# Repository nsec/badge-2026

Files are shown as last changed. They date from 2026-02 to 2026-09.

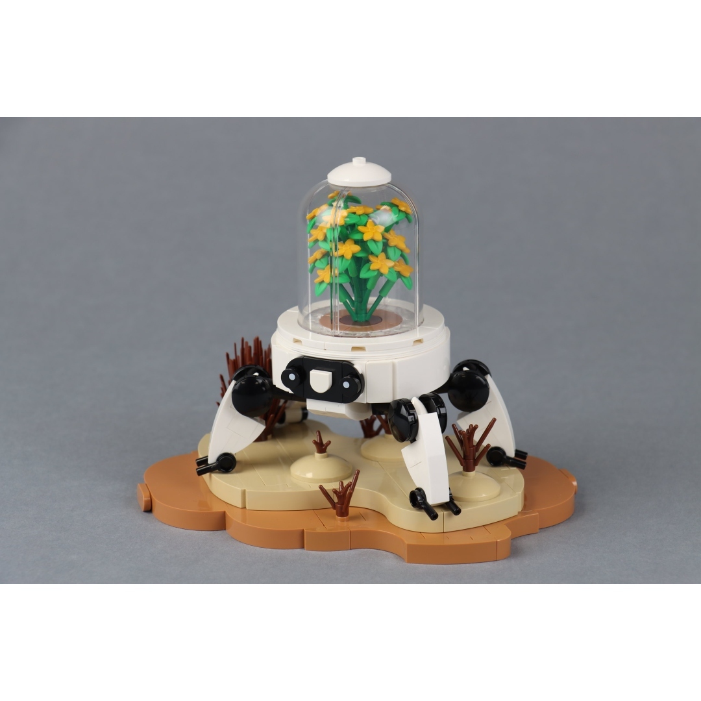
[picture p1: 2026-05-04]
hardware/sao/Sao_robotplant/625359624_18107269357665788_6827108831125513139_n.jpg

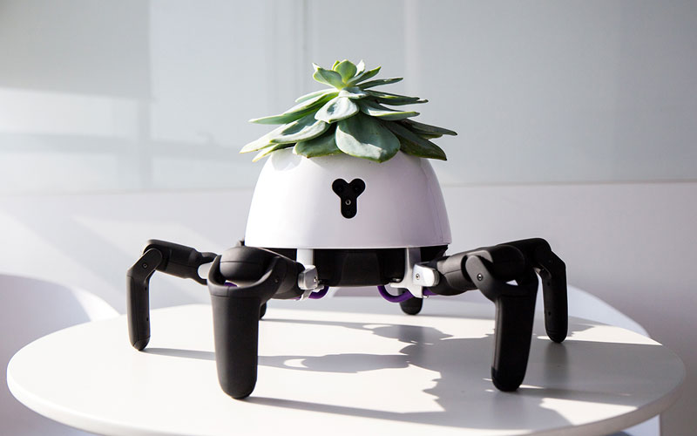
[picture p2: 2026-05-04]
hardware/sao/Sao_robotplant/guy-gives-plant-robotic-legs-so-it-can-experience-animal-like-freedom-1.jpg

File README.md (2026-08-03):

# NorthSec Badge 2026 Firmware (ESP32-S3)

Bare-bones firmware scaffold for the **NorthSec 2026 CTF badge**, targeting **ESP32-S3**.

Design goals (repo requirements):

- **Arduino framework**, but **no `.ino`** (pure C++ entrypoint)
- **PlatformIO-based** build (produces flashable `.bin` outputs)
- **Two concurrent firmware images** via partitions: **`conference`** and **`ctf`**
- A simple **serial CLI**, including a command to **switch which firmware boots next**
- Clear hierarchy separating:
  - `lib/core/` → hardware/system modules
  - `lib/challenges/` → CTF challenge modules
- GitHub Actions workflow builds on PR/push to `main`, and **publishes artifacts on version tags**

## Repo layout

```
src/
  main.cpp                     C++ Arduino entrypoint (no .ino)

lib/
  core/
    cli/                        Serial command line
    system/                     OTA boot selection / dual-firmware helpers
    hardware/                   Hardware abstraction (pins, drivers)
  challenges/
    registry.*                  Challenge init/tick hooks
    example_challenge.*         Placeholder challenge module

partitions/
  badge_factory_ota.csv         Partition table (conference + ctf)

.github/workflows/
  build.yml                     CI build + tag-based release

platformio.ini                  PlatformIO project config
```

## PlatformIO + Arduino (no .ino)

This project uses PlatformIO with the Arduino framework.
The entrypoint is `src/main.cpp` (standard Arduino `setup()` / `loop()`), not a `.ino`.

## Dual firmware: `conference` + `ctf`

The partition table `partitions/badge_factory_ota.csv` defines:

- `conference` (app) — a "golden" image
- `ctf` (app) — an alternate/updated image
- `otadata` (data) — controls which app partition boots next

### How switching works

Under Arduino-ESP32, you can call ESP-IDF’s OTA APIs. This repo wraps them in:

- `lib/core/system/ota_manager.*`

That module provides:

- `core::ota::printBootInfo(Stream&)`
- `core::ota::setNextBoot(BootTarget, Stream&)`

## Serial CLI

The CLI is implemented in `lib/core/cli/` and runs over `Serial` at **115200**.

Commands:

- `help`
- `info` — print running partition and configured boot partition
- `boot conference` — set *next boot* to `conference` and reboot
- `boot ctf` — set *next boot* to `ctf` and reboot
- `reboot`

## Building locally

### Prerequisites

- **VS Code** with **PlatformIO IDE extension** installed, **OR**
- **PlatformIO Core** (CLI) installed

### Windows Setup (Important!)

**This project uses ESP-IDF framework to avoid Windows path-length issues with Arduino-ESP32 SDK extraction.**

Before building, set a short PlatformIO core directory to prevent path issues:

```powershell
# Set environment variable permanently (restart VS Code after)
setx PLATFORMIO_CORE_DIR C:\pio
```

Then **restart VS Code** or your terminal.

### First-Time Setup

1. Clone this repository:
   ```powershell
   git clone https://github.com/yourusername/badge-2026.git
   cd badge-2026
   ```

2. Set the short core directory (Windows only, see above)

3. Open the project in VS Code with PlatformIO extension, or use CLI

### Build

**In VS Code:** Click the PlatformIO "Build" button (checkmark icon) in the bottom toolbar

**Or via CLI:**
```powershell
# Build for conference partition (default)
C:\pio\penv\Scripts\platformio.exe run -e esp32-s3-devkitc-1-conference

# Or if platformio is in PATH
pio run
```

First build will download Arduino-ESP32 framework and toolchains. Subsequent builds are much faster.

### Dual Firmware Build

The badge uses a **conference + CTF** partition layout for dual-firmware boot:

- **conference** partition (`0x10000`) - Conference/stable image
- **ctf** partition (`0x150000`) - CTF challenges image

**To flash both partitions:**

```powershell
# 1. Upload to conference partition
C:\pio\penv\Scripts\platformio.exe run -e esp32-s3-devkitc-1-conference -t upload

# 2. Upload the CTF firmware to ctf partition
C:\pio\penv\Scripts\platformio.exe run -e esp32-s3-devkitc-1-ctf -t upload
```

**In VS Code:** Use the environment switcher in the bottom toolbar to select `esp32-s3-devkitc-1-conference` or `esp32-s3-devkitc-1-ctf`, then click Upload.

After flashing both, you can use the badge CLI commands to switch between them:
- `boot conference` - Set next boot to conference partition
- `boot ctf` - Set next boot to ctf partition
- `info` - Show current boot partition

Build outputs (including flashable binaries) appear under:

- `.pio/build/<env>/firmware.bin`
- `.pio/build/<env>/bootloader.bin`
- `.pio/build/<env>/partitions.bin`

### Flash

If you have a board connected and the correct upload port set:

```powershell
pio run -t upload
```

### Monitor

```powershell
pio device monitor
```

## Native Simulator

A desktop simulator allows running the badge firmware on your development machine
without hardware. Useful for testing CLI commands, debugging, and development.

### Prerequisites

- PlatformIO Core (CLI)
- GCC with C++17 and pthread support (Linux/macOS)
- For Windows: WSL recommended

### First-Time Setup

Initialize the FreeRTOS submodule:

```bash
git submodule update --init --recursive
```

### Build

```bash
pio run -e native
```

### Run

```bash
./.pio/build/native/program
```

The simulator presents the same CLI as the real badge. Press `Ctrl+C` to exit.

## CI/CD - GitHub Actions Workflow

### Automated Builds

The workflow in `.github/workflows/build.yml` automatically builds firmware on:

- **Pull Requests** targeting `main` - Build verification
- **Push to `main`** - Build and upload artifacts
- **Version Tags** (`v*`) - Build, create GitHub Release with binaries

### What Gets Built

Both firmware variants are built in parallel:
- **Conference firmware** (`badge-conference.bin`) - Conference mode with schedule and social features
- **CTF firmware** (`badge-ctf.bin`) - CTF challenges mode
- Supporting files: `bootloader.bin`, `partitions.bin`

### Creating a Release

**Step 1: Open a Pull Request**
```bash
git checkout -b feature-my-changes
# Make your changes
git add .
git commit -m "Add new feature"
git push origin feature-my-changes
```
Open PR on GitHub targeting `main` branch. GitHub Actions will build and verify.

**Step 2: Merge to Main**
After review, merge the PR. This triggers a build and uploads artifacts.

**Step 3: Create a Release Tag**
```bash
# Pull latest main
git checkout main
git pull origin main

# Create and push version tag
git tag v1.0.0
git push origin v1.0.0
```

Or use GitHub's web interface:
1. Go to repository → Releases → "Create a new release"
2. Click "Choose a tag" → Type new tag (e.g., `v1.0.0`) → "Create new tag"
3. Set release title (e.g., "NorthSec Badge 2026 v1.0.0")
4. GitHub Actions will automatically build and attach binaries

### Release Artifacts

Each release includes:
- `badge-conference.bin` - Conference firmware for conference partition
- `badge-ctf.bin` - CTF challenges firmware for CTF partition
- `bootloader.bin` - ESP32-S3 bootloader
- `partitions.bin` - Partition table
- `FLASH_INSTRUCTIONS.txt` - Complete flashing guide

## Flashing Pre-Built Firmware

### Prerequisites

Install esptool:
```bash
pip install esptool
```

Find your serial port:
- **Windows**: Check Device Manager → Ports (COM & LPT) → Look for "USB Serial Device" (e.g., COM4)
- **Linux**: `ls /dev/ttyACM* /dev/ttyUSB*` (usually /dev/ttyACM0)
- **Mac**: `ls /dev/cu.*` (look for cu.usbmodem*)

### Download Release Files

Go to [Releases](https://github.com/yourusername/badge-2026/releases) and download the latest `.zip` or individual files.

### Flash All (Recommended for New Badges)

Flash bootloader, partition table, and both firmware images:

**Windows:**
```powershell
python -m esptool --chip esp32s3 --port COM4 --baud 460800 ^
  --before default_reset --after hard_reset write_flash -z ^
  --flash_mode dio --flash_freq 80m --flash_size 8MB ^
  0x0 bootloader.bin ^
  0x8000 partitions.bin ^
  0x10000 badge-conference.bin ^
  0x150000 badge-ctf.bin
```

**Linux/Mac:**
```bash
python3 -m esptool --chip esp32s3 --port /dev/ttyACM0 --baud 460800 \
  --before default_reset --after hard_reset write_flash -z \
  --flash_mode dio --flash_freq 80m --flash_size 8MB \
  0x0 bootloader.bin \
  0x8000 partitions.bin \
  0x10000 badge-conference.bin \
  0x150000 badge-ctf.bin
```

### Update Only Firmware (Keep Existing Bootloader/Partitions)

If badges are already initialized, flash only updated firmware:

**Conference firmware only:**
```bash
python -m esptool --chip esp32s3 --port <PORT> --baud 460800 \
  write_flash -z 0x10000 badge-conference.bin
```

**CTF firmware only:**
```bash
python -m esptool --chip esp32s3 --port <PORT> --baud 460800 \
  write_flash -z 0x150000 badge-ctf.bin
```

**Both firmwares:**
```bash
python -m esptool --chip esp32s3 --port <PORT> --baud 460800 \
  write_flash -z 0x10000 badge-conference.bin 0x150000 badge-ctf.bin
```

### Verify Flash

Connect to serial console at 115200 baud:
```bash
# Windows
python -m serial.tools.miniterm COM4 115200

# Linux/Mac
python3 -m serial.tools.miniterm /dev/ttyACM0 115200
```

You should see the boot banner and CLI prompt. Type `help` to see available commands.

### Switch Between Firmwares

At the CLI prompt:
- `boot conference` - Reboot to conference firmware
- `boot ctf` - Reboot to CTF challenges firmware
- `info` - Show current running partition

## Additional Documentation

- **[FLASHING.md](FLASHING.md)** - Complete flashing guide for mass production and distribution
- **[CONTRIBUTING.md](CONTRIBUTING.md)** - Developer guide for adding features and challenges
- **[.github/workflows/build.yml](.github/workflows/build.yml)** - CI/CD configuration reference

## Firmware Architecture

### Dual-Firmware Design

This badge uses a unique dual-firmware architecture:

- **Conference Partition (0x10000)** - Conference mode
  - Boots by default on new badges
  - Contains conference-specific features (schedule, social, etc.)
  - Libraries: `core` + `conference`
  
- **CTF Partition (0x150000)** - CTF Challenges mode
  - Accessible via `boot ctf` command
  - Contains competition challenges (crypto, hardware, etc.)
  - Libraries: `core` + `challenges`

Both firmwares share the `core` library (CLI, OTA management, hardware abstraction) but have completely different feature sets.

### Adding New Features

See [CONTRIBUTING.md](CONTRIBUTING.md) for detailed instructions on adding:
- Conference modules (conference firmware)
- Challenge modules (CTF firmware)
- Core utilities (shared by both)

## License

Apache-2.0 (see `LICENSE`).

## Credits
NorthSec CTF badge 2026 is brought to you by the teamwork of:

 - [20th](https://github.com/20th)
 - [Svieg](https://github.com/Svieg)
 - [TheKGBSpy](https://github.com/TheKGBSpy)
 - [jgalar](https://github.com/jgalar)
 - [lle](https://github.com/lle)
 - [mjeanson](https://github.com/mjeanson)
 - [nyx0](https://github.com/nyx0)
 - [p0ns](https://github.com/p0ns)
 - [padraignix](https://github.com/padraignix)

Special thanks to:
 - [Marc-Olivier](https://github.com/D3c4f-NS)
 - David

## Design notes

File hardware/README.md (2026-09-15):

This folder contains the design files of the NorthSec 2026 badge.

## Folder structure

| Folder | Content |
|:---|:---|
| boards | Kicad schematics & pcb layout |
| datasheets | datasheets of used electrical components |
| mechanical | Full FreeCAD 3d model of all components of flower |

## Schematic

**Interactive schematic:**

- [Open Badge schematics in KiCanvas](https://kicanvas.org/?repo=https%3A%2F%2Fgithub.com%2Fnsec%2Fbadge-2026%2Ftree%2Fmain%2Fhardware%2Fbadge)
- [Open Sun SAO schematics in KiCanvas](https://kicanvas.org/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)
- [Open Tree SAO schematics in KiCanvas](https://kicanvas.org/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)
- [Open Robotplant SAO schematics in KiCanvas](https://kicanvas.org/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)

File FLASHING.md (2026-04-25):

# Badge Flashing Guide

## Two Distribution Modes

The badge firmware supports two release packages:

| Mode | Use Case | Contents |
|---|---|---|
| **conference-only** | Pre-CTF badge distribution | Conference firmware only, no `swapboot`, no CTF code |
| **dual** | Full badge experience | Conference + CTF firmware, `swapboot` enabled |

## Requirements

- Python 3.7+ with esptool: `pip install esptool`
- USB-C data cable
- Badge firmware package from GitHub release

## Quick Flash (Recommended)

Each release package includes `flash.py`. Extract the package and run:

```bash
# Conference-only (pre-CTF distribution)
python flash.py --mode conference-only --port <PORT>

# Dual firmware (full badge)
python flash.py --mode dual --port <PORT>
```

### Options

| Flag | Description |
|---|---|
| `--mode` | `conference-only` or `dual` (required for flashing) |
| `--port` | Serial port, e.g. `COM4` or `/dev/ttyACM0` (auto-detect if omitted) |
| `--all` | Flash ALL detected ESP32-S3 badges in parallel |
| `--baud` | Baud rate (default: 460800) |
| `--dry-run` | Print the esptool command without executing |
| `--bin-dir` | Directory containing binaries (default: script directory) |
| `--list-ports` | Show all serial ports and exit |

### Examples

```bash
# Single badge (auto-detect port — works on Windows, macOS, Linux)
python flash.py --mode dual

# Single badge with explicit port
python flash.py --mode dual --port COM4              # Windows
python3 flash.py --mode conference-only --port /dev/ttyACM0  # Linux
python3 flash.py --mode dual --port /dev/cu.usbmodem*  # macOS

# Multi-flash: flash ALL connected badges at once
python flash.py --mode conference-only --all

# Preview without flashing
python flash.py --mode dual --all --dry-run

# Debug port detection
python flash.py --list-ports
```

### Erase (Wipe Badge Clean)

```bash
# Erase a single badge
python flash.py --erase

# Erase a specific port
python flash.py --erase --port COM4

# Erase ALL connected badges
python flash.py --erase --all
```

After erasing, reflash with the desired mode.

### Multi-Flash (Mass Production)

Connect multiple badges via USB hubs, then:

```bash
python flash.py --mode conference-only --all
```

All detected ESP32-S3 badges flash in parallel. A summary report shows success/failure per port.

## Manual Flash (esptool)

### Conference-Only

```bash
python -m esptool --chip esp32s3 --port <PORT> --baud 460800 \
  --before default_reset --after hard_reset write_flash -z \
  --flash_mode dio --flash_freq 80m --flash_size 8MB \
  0x0 bootloader.bin \
  0x8000 partitions.bin \
  0x10000 badge-conference.bin \
  0x2A2000 spiffs-conference.bin
```

### Dual Firmware

```bash
python -m esptool --chip esp32s3 --port <PORT> --baud 460800 \
  --before default_reset --after hard_reset write_flash -z \
  --flash_mode dio --flash_freq 80m --flash_size 8MB \
  0x0 bootloader.bin \
  0x8000 partitions.bin \
  0x10000 badge-conference.bin \
  0x150000 badge-ctf.bin \
  0x2A2000 spiffs-ctf.bin
```

## Memory Map

| Address | Size | Content | Present In |
|---|---|---|---|
| 0x0 | ~15KB  | bootloader.bin | Both modes |
| 0x8000 | 3KB | partitions.bin | Both modes |
| 0xE000 | 8KB | OTA data selector | Auto |
| 0x10000 | 1.25MB | badge-conference.bin | Both modes |
| 0x150000 | 1.25MB | badge-ctf.bin | Dual only |
| 0x290000 | 64KB | Core dump partition  | Auto |
| 0x2A2000 | ~1.4MB | SPIFFS filesystem | Both (mode-specific)|

## Verification Checklists

### Conference-Only

After flashing:
- [ ] Boot banner shows `Mode: conference-only`
- [ ] CLI `help` does NOT list `swapboot`
- [ ] LED heartbeat blinks
- [ ] CLI commands respond

### Dual Firmware

After flashing:
- [ ] Boot banner shows `Mode: conference (dual)`
- [ ] CLI `help` lists `swapboot`
- [ ] `swapboot` reboots to CTF firmware
- [ ] CTF boot banner shows `Mode: ctf`
- [ ] `swapboot` returns to conference firmware

## Troubleshooting

**"Failed to connect":**
- Hold BOOT button while connecting USB
- Try lower baud rate: `--baud 115200`
- Check USB cable supports data (not charge-only)

**Badge not working after flash:**
- Erase flash: `python -m esptool --chip esp32s3 --port <PORT> erase_flash`
- Reflash all files

**Wrong partition boots:**
- Use CLI `swapboot` command
- Or reflash with the correct package

## Support

For issues: https://github.com/nsec/badge-2026/issues

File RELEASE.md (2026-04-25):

# Release Process

For maintainers creating firmware releases.

## Two Release Modes

Every release produces **two** packages:

| Package | Purpose | Contents |
|---|---|---|
| `nsec2026-conference-only-vX.Y.Z.tar.gz` | Pre-CTF distribution | Conference firmware only, `swapboot` disabled |
| `nsec2026-dual-firmware-vX.Y.Z.tar.gz` | Full badge experience | Conference + CTF firmware, `swapboot` enabled |

## Build Environments

| PIO Environment | Build Flag | Used In |
|---|---|---|
| `esp32-s3-devkitc-1-conference` | `HAS_CONFERENCE=1` | Dual package |
| `esp32-s3-devkitc-1-conference-only` | `HAS_CONFERENCE=1 CONFERENCE_ONLY=1` | Conference-only package |
| `esp32-s3-devkitc-1-ctf` | `HAS_CHALLENGES=1` | Dual package |

## Pre-Release Testing

### Conference-Only
- [ ] Build succeeds: `pio run -e esp32-s3-devkitc-1-conference-only`
- [ ] Flash and verify boot banner shows `Mode: conference-only`
- [ ] CLI `help` does **not** show `swapboot`
- [ ] Validation passes: `python tools/validate_conference_only.py release/conference-only/`

### Dual Firmware
- [ ] Build succeeds: `pio run -e esp32-s3-devkitc-1-conference -e esp32-s3-devkitc-1-ctf`
- [ ] Conference boot banner shows `Mode: conference (dual)`
- [ ] `swapboot` switches to CTF firmware
- [ ] CTF boot banner shows `Mode: ctf`
- [ ] `swapboot` returns to conference firmware

### General
- [ ] All PRs merged to `main`
- [ ] No compilation warnings
- [ ] Memory usage acceptable

## Creating a Release

### Step 1: Build and Package Locally (Optional)

```bash
# Build all three environments (SPIFFS images are built automatically)
pio run -e esp32-s3-devkitc-1-conference-only
pio run -e esp32-s3-devkitc-1-conference
pio run -e esp32-s3-devkitc-1-ctf

# Package
python tools/package_release.py --version vX.Y.Z

# Validate conference-only package
python tools/validate_conference_only.py release/conference-only/
```

### Step 2: Tag and Push

```bash
git checkout main
git pull origin main
git tag -a v1.0.0 -m "Release v1.0.0"
git push origin v1.0.0
```

### Step 3: CI Builds Automatically

The GitHub Actions workflow will:
1. Build all three firmware environments (SPIFFS images are built automatically)
2. Package both release modes
3. Validate conference-only package (no CTF leaks)
4. Create GitHub Release with both archives

### Step 4: Verify Release

1. Go to Releases page
2. Verify two archives are attached:
   - `nsec2026-conference-only-vX.Y.Z.tar.gz`
   - `nsec2026-dual-firmware-vX.Y.Z.tar.gz`
3. Download and spot-check `manifest.json` in each

## Version Numbering

Semantic versioning: `vMAJOR.MINOR.PATCH`

- **MAJOR**: Breaking changes
- **MINOR**: New features (e.g. new challenge module)
- **PATCH**: Bug fixes

## CTF Content Safety

The conference-only release must **never** contain:
- CTF firmware binary (`badge-ctf.bin`)
- The `swapboot` CLI command
- Challenge code or strings (quantum, QAOA, VQE, etc.)
- Flag patterns (`NSEC{...}`)

**Guardrails in place:**
1. `CONFERENCE_ONLY` build flag compiles out `swapboot` and prevents `HAS_CHALLENGES`
2. `#error` in `badge_config.h` if both `CONFERENCE_ONLY` and `HAS_CHALLENGES` are set
3. `validate_conference_only.py` scans binary for forbidden patterns
4. CI runs validation on every build

## Adding New CTF Content

When adding new challenges:
1. Place code in `lib/challenges/<name>/`
2. Register in `lib/challenges/registry.cpp`
3. Update `tools/validate_conference_only.py` with new forbidden patterns if the challenge introduces distinctive strings
4. Verify conference-only validation still passes

## Hotfix Process

```bash
git checkout v1.0.0
git checkout -b hotfix/critical-bug
# ... fix ...
git commit -m "fix: resolve critical issue"
git push origin hotfix/critical-bug
# PR to main, then tag v1.0.1
```

## Rollback

1. Mark release as "Pre-release" in GitHub
2. Add warning to release notes
3. Point users to previous stable version

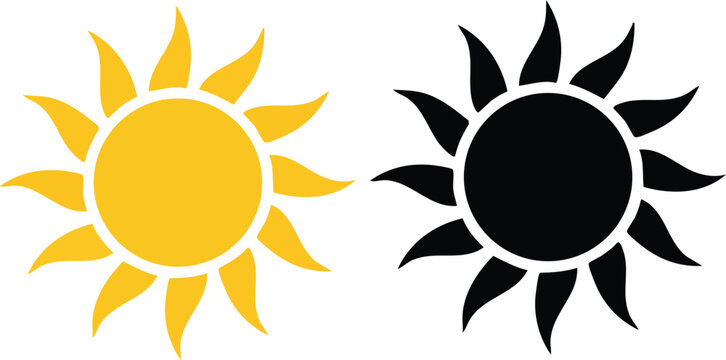
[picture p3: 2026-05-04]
hardware/sao/Sao_SUN/360_F_1957418534_RpFVAgXwyXc0LUIITzXDONv8gdVU5Ix7.jpg

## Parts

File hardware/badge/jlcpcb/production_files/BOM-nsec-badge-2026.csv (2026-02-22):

Comment | Designator | Footprint | LCSC | Quantity
0.1uF | C501,C502,C503,C504,C505,C506,C507,C508,C509,C510,C511,C512,C513,C514,C515,C516,C517,C518 | C_0603_1608Metric | C14663 | 18
0.1uF | C1101,C202 | C_0603_1608Metric | C28233 | 2
0.47 | R1202 | R_0603_1608Metric | C23411 | 1
100K | R805 | R_0603_1608Metric | C14675 | 1
100K | R302 | R_0603_1608Metric | C25803 | 1
10K | R201,R202,R204,R601,R602,R603,R604,R605,R606 | R_0603_1608Metric | C25804 | 9
10nF | C1001,C1003,C1006,C1009,C1011,C1013,C1015,C1019 | C_0603_1608Metric | C57112 | 8
10pF | C1032,C1035 | C_0603_1608Metric | C1634 | 2
10uF | C201,C302,C802 | C_0805_2012Metric | C15850 | 3
10uH | L1201 | L_Vishay_IFSC-1515AH_4x4x1.8mm | C222882 | 1
12pF | C1007,C1008 | C_0603_1608Metric | C38523 | 2
150pF | C1028,C1029 | C_0603_1608Metric | C1594 | 2
1K | R1001 | R_0603_1608Metric | C14676 | 1
1K | R203,R801,R802,R803 | R_0603_1608Metric | C21190 | 4
1R5 | R1004,R1005 | R_0603_1608Metric | C245932 | 2
1nF | C1017 | C_0603_1608Metric | C1588 | 1
1uF | C1004,C1201,C1202,C1203,C1204,C1205,C1206,C1207,C1208,C1209,C1211,C203,C301,C303 | C_0603_1608Metric | C15849 | 14
1uF | C803 | C_0805_2012Metric_Pad1.18x1.45mm_HandSolder | C28323 | 1
220pF | C1033,C1034 | C_0603_1608Metric | C1603 | 2
22nF | C1018 | C_0603_1608Metric | C21122 | 1
27.12Mhz | Y1001 | Crystal_SMD_3225-4Pin_3.2x2.5mm | C3003244 | 1
2u2F | C1002,C1005,C1010,C1012,C1014,C1016 | C_0603_1608Metric | C23630 | 6
33pF | C1023,C1024 | C_0603_1608Metric | C1663 | 2
390K | R804 | R_0603_1608Metric | C23150 | 1
4.7uF | C801 | C_0805_2012Metric_Pad1.18x1.45mm_HandSolder | C1779 | 1
4.7uF/50V | C1210,C1212 | C_1206_3216Metric | C29823 | 2
47pF | C1030,C1031 | C_0603_1608Metric | C1671 | 2
4u7F | C1020 | C_0603_1608Metric | C19666 | 1
5.1K | R301,R303,R401,R402 | R_0603_1608Metric | C23186 | 4
680pF | C1021,C1022 | C_0603_1608Metric | C107055 | 2
AP2112K-3_3TRG1 | U301 | SOT-25-5_L2.9-W1.6-P0.95-LS2.8-BL | C47719 | 1
ESP32-S3-WROOM-1(N16R8) | U201 | WIRELM-SMD_ESP32-S3-WROOM-1 | C2913202 | 1
HC-FPC-05-09-24RLTAG | U1202 | FPC-SMD_24P-P0.50_HC-FPC-05-09-24RLTAG | C5213757 | 1
IRLML0100TRPBF | Q1201 | SOT-23-3 | C53658 | 1
LXRW0YV600-054 | C1025,C1026,C1027 | X2SON-4_L0.6-W0.6-P0.40-BL | C2988749 | 3
MBR0530 | D1201,D1202,D1203 | D_SOD-123 | C77336 | 3
MBR120LSF | D301,D302 | SOD-123_L2.8-W1.8-LS3.7-RD | C130880 | 2
MLJ1608WR27JT000 | L1001,L1002 | L_0603_1608Metric | C2041707 | 2
NCD0805R1 | LED1001,LED201,LED301,LED302,LED801 | LED_0805_2012Metric_Pad1.15x1.40mm_HandSolder | C84256 | 5
PM254-2-03-S-8_5 | J701,J702 | HDR-SMD_6P-P2.54-V-F-R2-C3-LS7.0 | C3975148 | 2
SK6812SIDE-A_C5378721 | RGB501,RGB502,RGB503,RGB504,RGB505,RGB506,RGB507,RGB508,RGB509,RGB510,RGB511,RGB512,RGB513,RGB514,RGB515,RGB516,RGB517,RGB518 | LED-SMD_SK6812SIDE-A_C5378721 | C5378721 | 18
SSSS811101 | KEY301 | SW-SMD_SSSS811101 | C109335 | 1
ST25R3916-AQWT | U1001 | QFN50P500X500X100-33N-D | C2908147 | 1
TPSMF05CT1G | U402 | SOT-363_L2.0-W1.3-P0.65-LS2.1-BL | C558443 | 1
TS-1187A-C-C-B | SW201,SW202,SW601,SW602,SW603,SW604,SW605,SW606 | SW-SMD_4P-L5.1-W5.1-P3.70-LS6.5-TL_H1.5 | C318889 | 8
TYPE-C-31-M-12 | U401 | USB-C_SMD-TYPE-C-31-M-12 | C165948 | 1
VEML6040A3OG | U1101 | SENSOR_SMD_VEML6040A3OG | C78465 | 1
XDWF-0920-02P | U802 | CONN-SMD_XDWF-0920-02P | C7527581 | 1
XT4054K421MR-G | U801 | SOT-23-5_L3.0-W1.7-P0.95-LS2.8-BL | C141405 | 1

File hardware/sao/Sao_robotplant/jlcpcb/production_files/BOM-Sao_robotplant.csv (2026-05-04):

Comment | Designator | Footprint | LCSC | Quantity
LED | D1 | LED_D3.0mm |  | 1
330 | R1 | R_Axial_DIN0204_L3.6mm_D1.6mm_P7.62mm_Horizontal |  | 1
SAO Connector SMD | J1 | SAO Connector SMD |  | 1

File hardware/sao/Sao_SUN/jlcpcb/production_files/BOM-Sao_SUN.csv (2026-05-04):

Comment | Designator | Footprint | LCSC | Quantity
LED | D2 | LED_1206_3216Metric_Pad1.42x1.75mm_HandSolder |  | 1
LED | D3 | LED_1206_3216Metric_Pad1.42x1.75mm_HandSolder |  | 1
LED | D1 | LED_1206_3216Metric_Pad1.42x1.75mm_HandSolder |  | 1
330 | R1 | R_1206_3216Metric_Pad1.30x1.75mm_HandSolder |  | 1
330 | R2 | R_1206_3216Metric_Pad1.30x1.75mm_HandSolder |  | 1
SAO Connector SMD | J1 | SAO Connector SMD |  | 1
330 | R3 | R_1206_3216Metric_Pad1.30x1.75mm_HandSolder |  | 1

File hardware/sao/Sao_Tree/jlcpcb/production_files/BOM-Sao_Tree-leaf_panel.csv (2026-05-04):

Comment | Designator | Footprint | LCSC | Quantity
LED | D3 | LED_0805_2012Metric |  | 1
Conn_01x02_Socket |  | PinSocket_1x02_P2.00mm_Vertical |  | 0
LED | D1 | LED_1206_3216Metric |  | 1
Conn_01x02_Socket |  | PinSocket_1x02_P2.00mm_Vertical |  | 0
Conn_01x02_Socket |  | PinSocket_1x02_P2.00mm_Vertical |  | 0
LED | D2 | LED_D5.0mm |  | 1

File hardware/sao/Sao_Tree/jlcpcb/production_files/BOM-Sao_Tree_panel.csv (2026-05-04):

Comment | Designator | Footprint | LCSC | Quantity
LED | D1 | LED_1206_3216Metric |  | 1
Conn_01x02_Socket |  | PinSocket_1x02_P2.00mm_Vertical |  | 0
330 | R4 | R_Axial_DIN0204_L3.6mm_D1.6mm_P7.62mm_Horizontal |  | 1
Conn_01x02_Socket |  | PinSocket_1x02_P2.00mm_Vertical |  | 0
330 | R1 | R_Axial_DIN0204_L3.6mm_D1.6mm_P7.62mm_Horizontal |  | 1
Conn_01x02_Socket |  | PinSocket_1x02_P2.00mm_Vertical |  | 0
330 | R3 | R_Axial_DIN0204_L3.6mm_D1.6mm_P7.62mm_Horizontal |  | 1
330 | R2 | R_Axial_DIN0204_L3.6mm_D1.6mm_P7.62mm_Horizontal |  | 1
SAO Connector SMD | J1 | SAO Connector SMD |  | 1

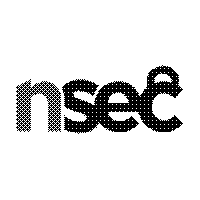
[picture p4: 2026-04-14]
nsec_200x200_bw_ordered.bmp

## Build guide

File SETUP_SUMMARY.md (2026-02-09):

# NorthSec Badge 2026 - Complete Setup Summary

## 🎯 What You Have

A complete dual-firmware badge system with:
- **Conference firmware** - Conference features (schedule, social)
- **CTF firmware** - CTF challenges (crypto, puzzles)
- **CLI system** - Boot partition switching and modular commands
- **CI/CD pipeline** - Automated builds and releases
- **Complete documentation** - For developers, users, and production

## 📁 Repository Structure

```
badge-2026/
├── .github/workflows/
│   └── build.yml              # CI/CD: Build on PR, push, tags
├── lib/
│   ├── core/                  # Shared by both firmwares
│   │   ├── cli/               # Command-line interface
│   │   ├── hardware/          # Hardware abstraction
│   │   └── system/            # OTA boot management
│   ├── conference/            # Conference firmware only
│   │   ├── schedule.*         # Conference schedule module
│   │   └── registry.*         # Conference module loader
│   └── challenges/            # CTF firmware only
│       ├── crypto.*           # Crypto challenge module
│       └── registry.*         # Challenge module loader
├── partitions/
│   └── badge_factory_ota.csv  # Dual-partition layout
├── src/
│   └── main.cpp               # Arduino entry point
├── platformio.ini             # Build configuration
├── README.md                  # Main documentation
├── FLASHING.md                # Production flashing guide
├── CONTRIBUTING.md            # Developer guide
├── RELEASE.md                 # Release process for maintainers
└── LICENSE                    # Apache-2.0
```

## 🚀 Quick Start for Developers

### Setup
```powershell
# Windows: Set short path first
setx PLATFORMIO_CORE_DIR C:\pio

# Clone and build
git clone <repo-url>
cd badge-2026
C:\pio\penv\Scripts\platformio.exe run
```

### Daily Development
```powershell
# Build and flash both firmwares
C:\pio\penv\Scripts\platformio.exe run -t upload

# Or individually
C:\pio\penv\Scripts\platformio.exe run -e esp32-s3-devkitc-1-conference -t upload        # Conference
C:\pio\penv\Scripts\platformio.exe run -e esp32-s3-devkitc-1-ctf -t upload    # CTF
```

### Add New Feature
1. Create module files in `lib/core`, `lib/conference/` or `lib/challenges/`
2. Register in respective `registry.cpp`
3. Test locally
4. Create PR to `main`

## 🔄 Workflow: Code → Production

### 1. Development
```bash
git checkout -b feature-new-module
# ... make changes ...
git commit -m "feat: add new module"
git push origin feature-new-module
```

### 2. Pull Request
- Open PR on GitHub targeting `main`
- GitHub Actions builds both firmwares
- Review and merge

### 3. Create Release
```bash
git checkout main
git pull
git tag v1.0.0
git push origin v1.0.0
```

### 4. Automated Release
GitHub Actions automatically:
- Builds conference firmware → `badge-conference.bin`
- Builds CTF firmware → `badge-ctf.bin`
- Packages bootloader and partitions
- Creates GitHub Release with all files
- Attaches `FLASH_INSTRUCTIONS.txt`

### 5. Distribution
Download from GitHub Releases and flash:
```bash
python -m esptool --chip esp32s3 --port <PORT> write_flash -z \
  0x0 bootloader.bin 0x8000 partitions.bin \
  0x10000 badge-conference.bin 0x150000 badge-ctf.bin
```

## 📚 Documentation Index

| File | Audience | Purpose |
|---|---|---|
| [README.md](README.md) | Everyone | Setup, build, usage |
| [FLASHING.md](FLASHING.md) | Production/Distribution | Mass flashing guide |
| [CONTRIBUTING.md](CONTRIBUTING.md) | Developers | Adding features |
| [RELEASE.md](RELEASE.md) | Maintainers | Release process |

## 🎮 Using the Badge

### Default Boot (Conference Mode)
```
> help
Commands:
  help       - show this help
  info       - partition info
  boot ctf   - switch to CTF mode
  schedule   - conference schedule
  ...

> schedule
=== NorthSec 2026 Schedule ===
...
```

### Switch to CTF (Challenges Mode)
```
> boot ctf
Rebooting to CTF challenges...

> help
Commands:
  help         - show this help
  info         - partition info
  boot conference - switch to conference mode
  crypto       - crypto challenge
  ...

> crypto
=== Crypto Challenge: The Cipher ===
...
```

## 🏭 Production Flashing

For mass production, see [FLASHING.md](FLASHING.md):
- Batch scripts included
- Quality assurance checklist
- Troubleshooting guide
- Memory map reference

## 🔧 Technical Details

### Memory Layout
```
0x000000   Bootloader (~15KB)
0x008000   Partition table (3KB)
0x00E000   OTA data selector (8KB)
0x010000   Conference firmware (1.25MB) - Conference
0x150000   CTF firmware (1.25MB) - Challenges
0x290000   Core dump (64KB)
0x2A0000   SPIFFS filesystem (1.4MB)
```

### Build System
- **PlatformIO** - Build framework
- **Arduino-ESP32** - Framework (via GitHub to avoid Windows issues)
- **Two environments**:
  - `esp32-s3-devkitc-1-conference` - Conference build with `HAS_CONFERENCE=1`
  - `esp32-s3-devkitc-1-ctf` - CTF build with `HAS_CHALLENGES=1`

### Module System
- Modular design - each feature in its own file
- Auto-registration via `registry.cpp`
- CLI commands registered at init
- Add/remove by including/excluding files

## ✅ Pre-Merge Checklist

Before merging to `main`:
- [ ] Both firmwares build successfully
- [ ] Tested on hardware
- [ ] CLI commands work
- [ ] Boot switching functional
- [ ] No compiler warnings
- [ ] Documentation updated

## 🎉 First Release Checklist

Ready for v1.0.0:
- [ ] All documentation complete
- [ ] Hardware tested thoroughly
- [ ] GitHub Actions workflow tested
- [ ] Flash instructions verified
- [ ] Quality assurance process defined
- [ ] Support channels established

## 🆘 Getting Help

- **Build issues?** Check [README.md](README.md) Windows setup section
- **Flashing issues?** See [FLASHING.md](FLASHING.md) troubleshooting
- **Contributing?** Read [CONTRIBUTING.md](CONTRIBUTING.md)
- **Questions?** Open GitHub Discussion
- **Bugs?** Open GitHub Issue

## 🎓 Next Steps

1. **Test the workflow**: Create a test PR and tag to verify CI/CD
2. **Add more modules**: Build out conference and challenge features
3. **Hardware customization**: Update `board_pins.h` with real pin mappings
4. **Production planning**: Review [FLASHING.md](FLASHING.md) for mass production
5. **Beta testing**: Flash test badges and gather feedback

## 🏆 Success Criteria

You'll know everything works when:
1. ✅ Push code → PR builds automatically
2. ✅ Merge → `main` builds successfully  
3. ✅ Tag `v1.0.0` → Release created with binaries
4. ✅ Download → Flash → Badge boots
5. ✅ Type `help` → See commands
6. ✅ Type `boot ctf` → Switches firmware
7. ✅ Type `boot conference` → Returns to conference mode

---

**You're ready to ship! 🚀**

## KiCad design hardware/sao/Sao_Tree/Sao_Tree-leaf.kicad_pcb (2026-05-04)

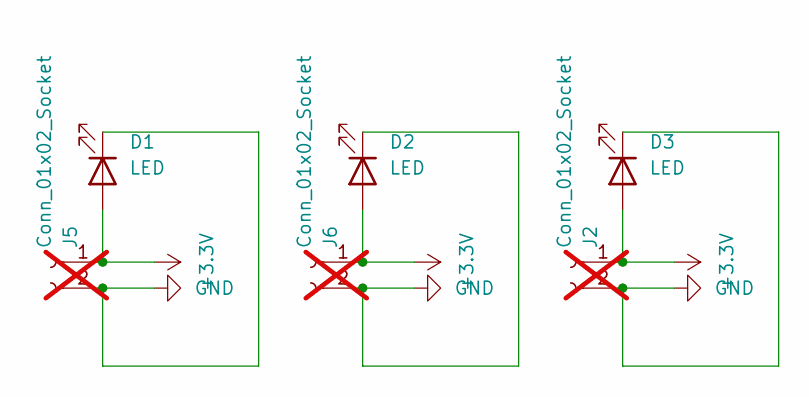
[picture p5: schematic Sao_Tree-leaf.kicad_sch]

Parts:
D1: LED; LED_1206_3216Metric
D2: LED; LED_D5.0mm
D3: LED; LED_0805_2012Metric
J2, J5, J6: Conn_01x02_Socket; PinSocket_1x02_P2.00mm_Vertical; not fitted

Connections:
+3.3V: D1.2 (A), D2.2 (A), D3.2 (A), J2.1, J5.1, J6.1
GND: D1.1 (K), D2.1 (K), D3.1 (K), J2.2, J5.2, J6.2

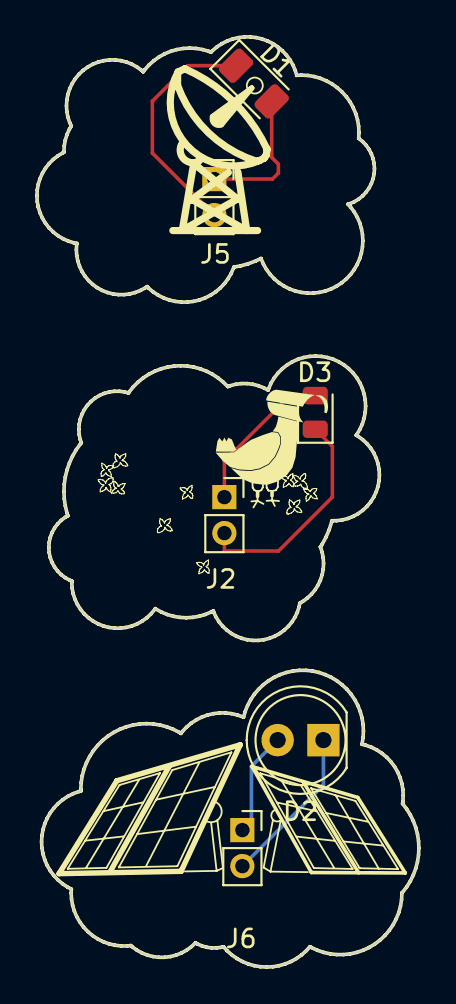
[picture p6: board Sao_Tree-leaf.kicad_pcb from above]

Board: 2 copper layers, 21.2 x 51.7 mm, 9 parts (0 on the bottom side), 2 nets.

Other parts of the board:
B1, B2, B3: Board

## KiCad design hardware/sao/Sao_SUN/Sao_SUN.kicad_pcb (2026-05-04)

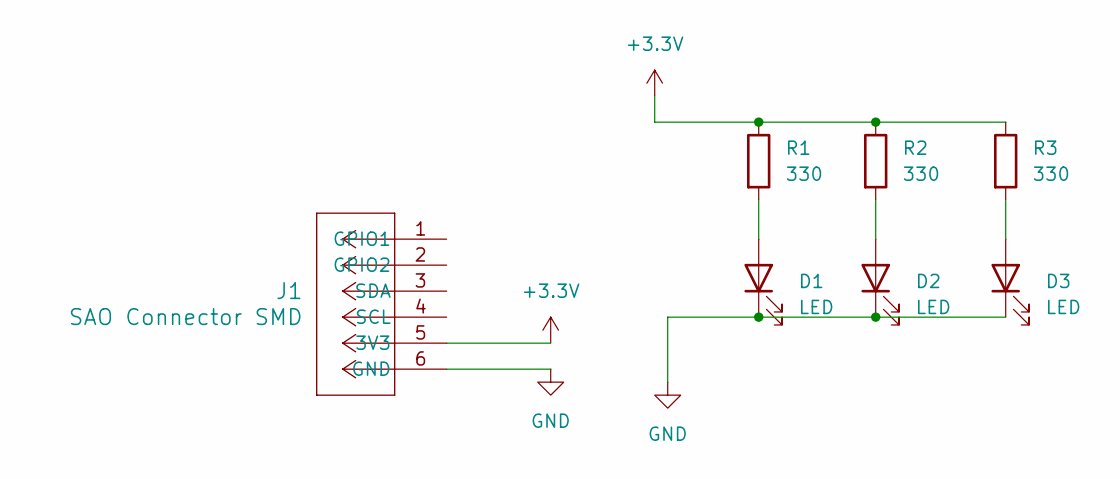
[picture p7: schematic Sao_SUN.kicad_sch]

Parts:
D1, D2, D3: LED; LED_1206_3216Metric_Pad1.42x1.75mm_HandSolder
J1: SAO Connector SMD
R1, R2, R3: 330; R_1206_3216Metric_Pad1.30x1.75mm_HandSolder

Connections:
+3.3V: J1.5 (3V3), R1.1, R2.1, R3.1
GND: D1.1 (K), D2.1 (K), D3.1 (K), J1.6 (GND)
unnamed: D1.2 (A), R1.2
unnamed: D2.2 (A), R2.2
unnamed: D3.2 (A), R3.2

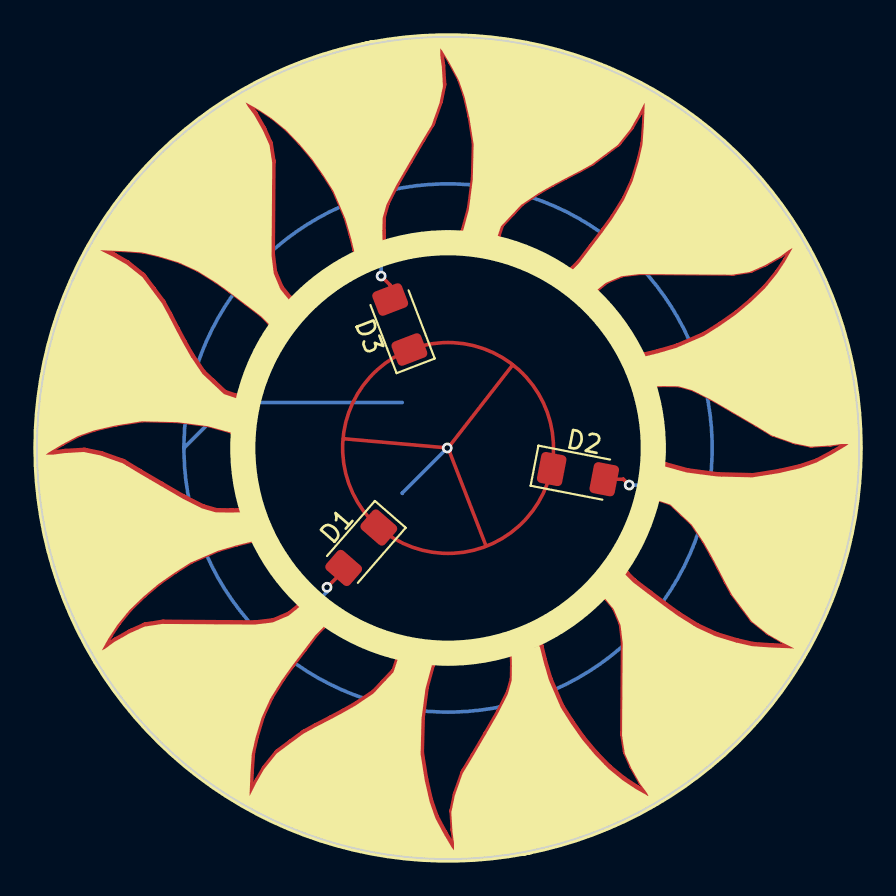
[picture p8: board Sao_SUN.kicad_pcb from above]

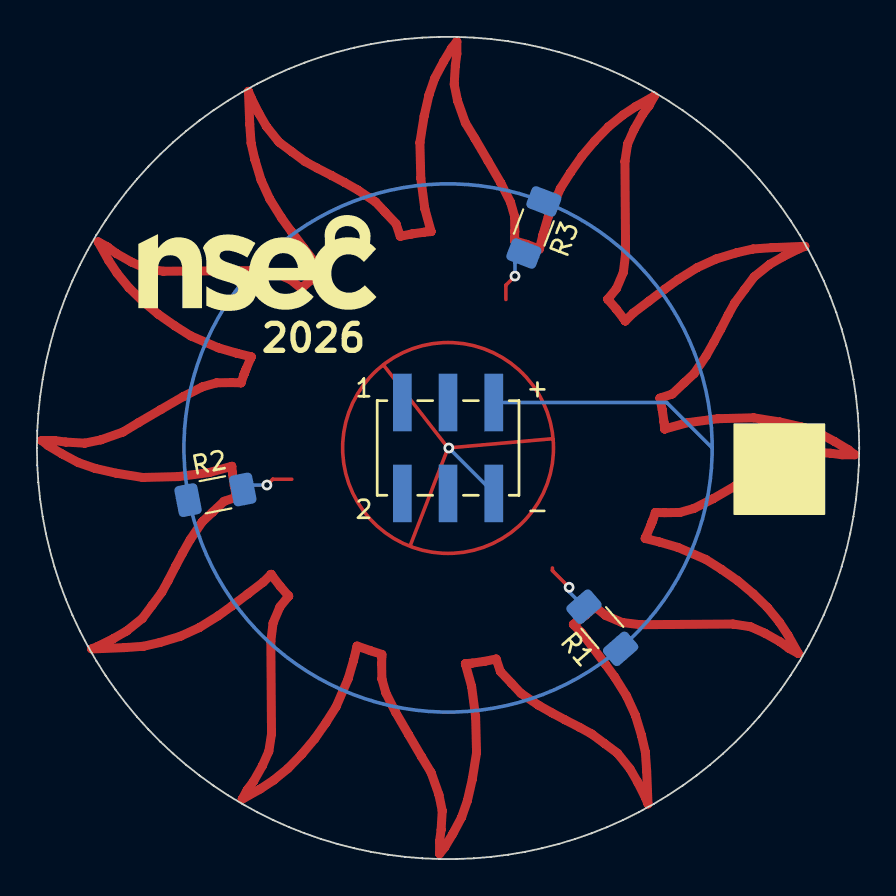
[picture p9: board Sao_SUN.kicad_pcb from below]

Board: 2 copper layers, 45.7 x 45.7 mm, 7 parts (4 on the bottom side), 5 nets.

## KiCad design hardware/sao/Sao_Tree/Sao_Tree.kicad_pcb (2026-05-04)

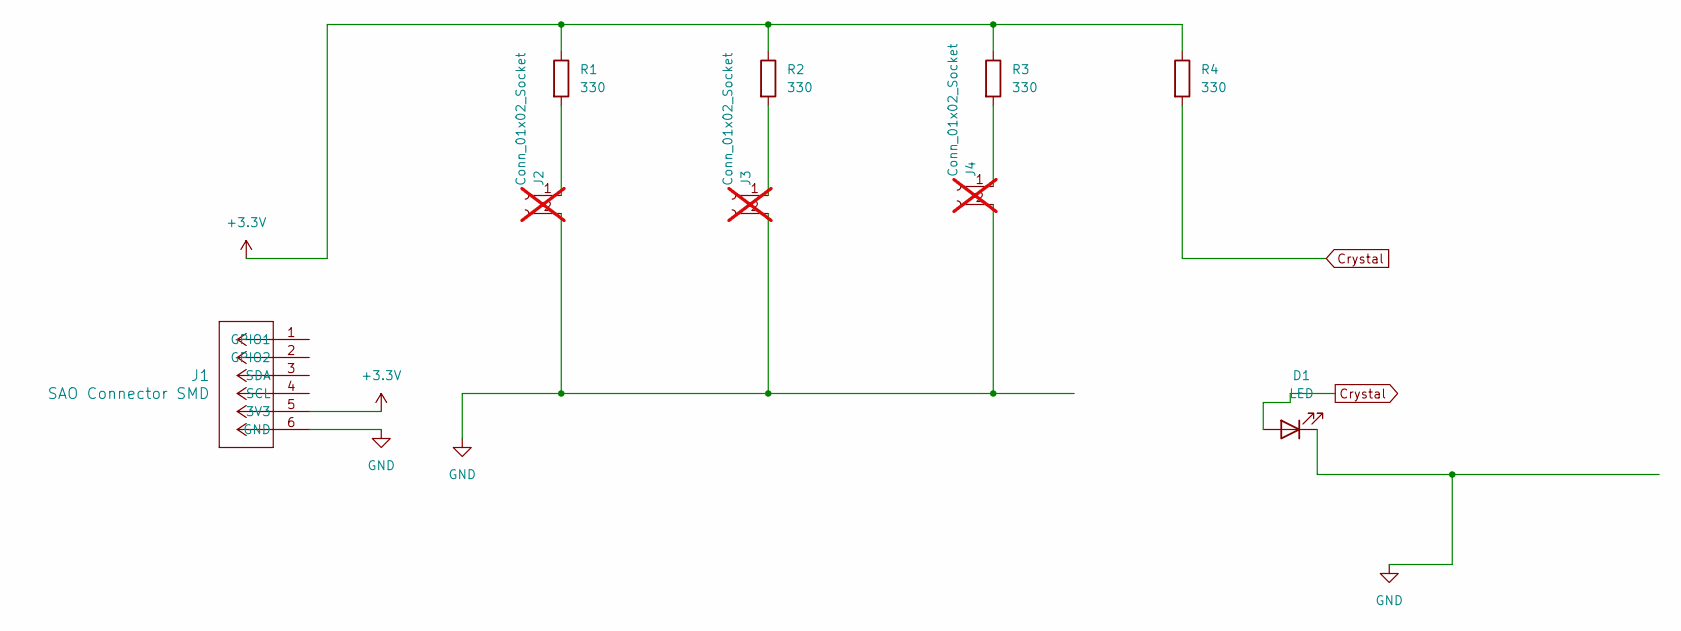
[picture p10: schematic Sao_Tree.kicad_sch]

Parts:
D1: LED; LED_1206_3216Metric
J1: SAO Connector SMD
J2, J3, J4: Conn_01x02_Socket; PinSocket_1x02_P2.00mm_Vertical; not fitted
R1, R2, R3, R4: 330; R_Axial_DIN0204_L3.6mm_D1.6mm_P7.62mm_Horizontal

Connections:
+3.3V: J1.5 (3V3), R1.1, R2.1, R3.1, R4.1
Crystal: D1.2 (A), R4.2
GND: D1.1 (K), J1.6 (GND), J2.2, J3.2, J4.2
unnamed: J2.1, R1.2
unnamed: J3.1, R2.2
unnamed: J4.1, R3.2

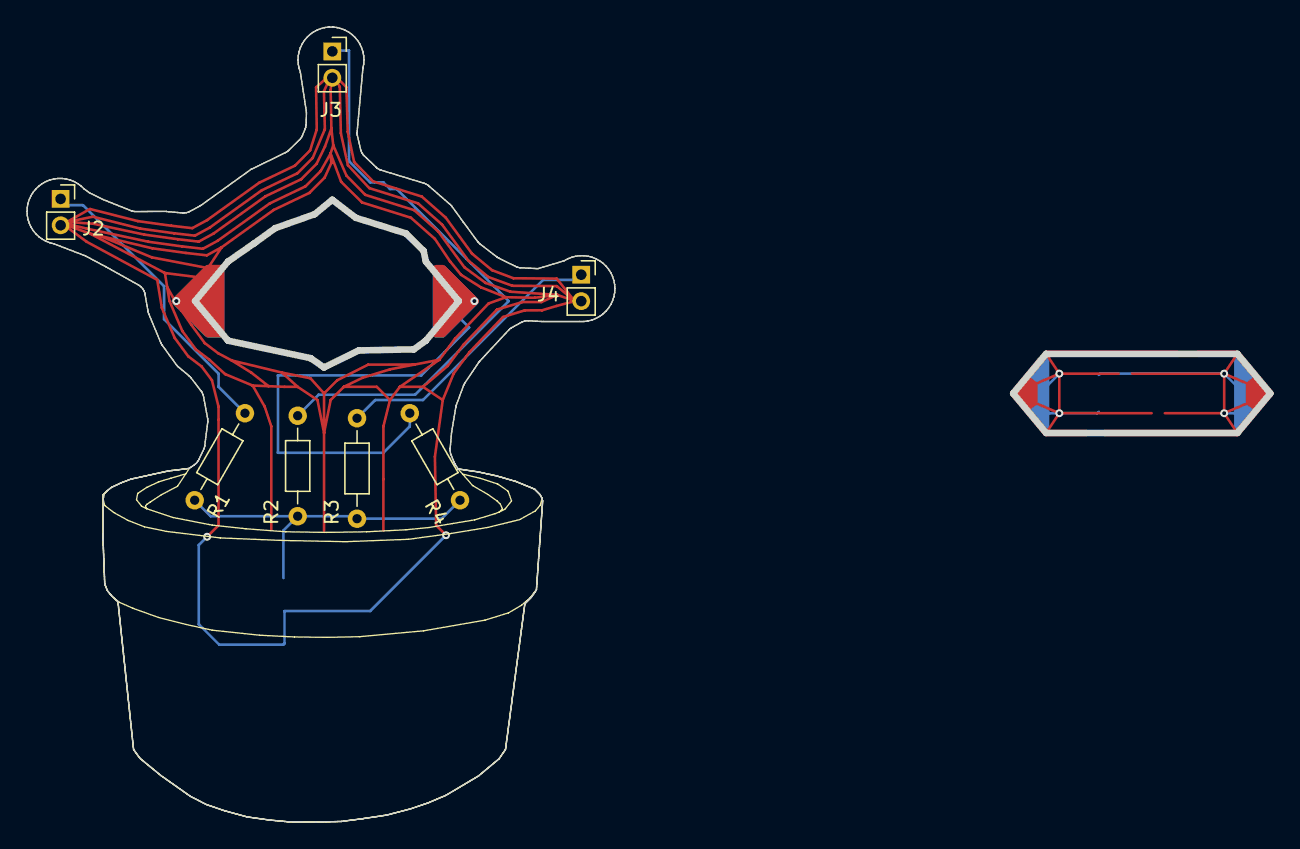
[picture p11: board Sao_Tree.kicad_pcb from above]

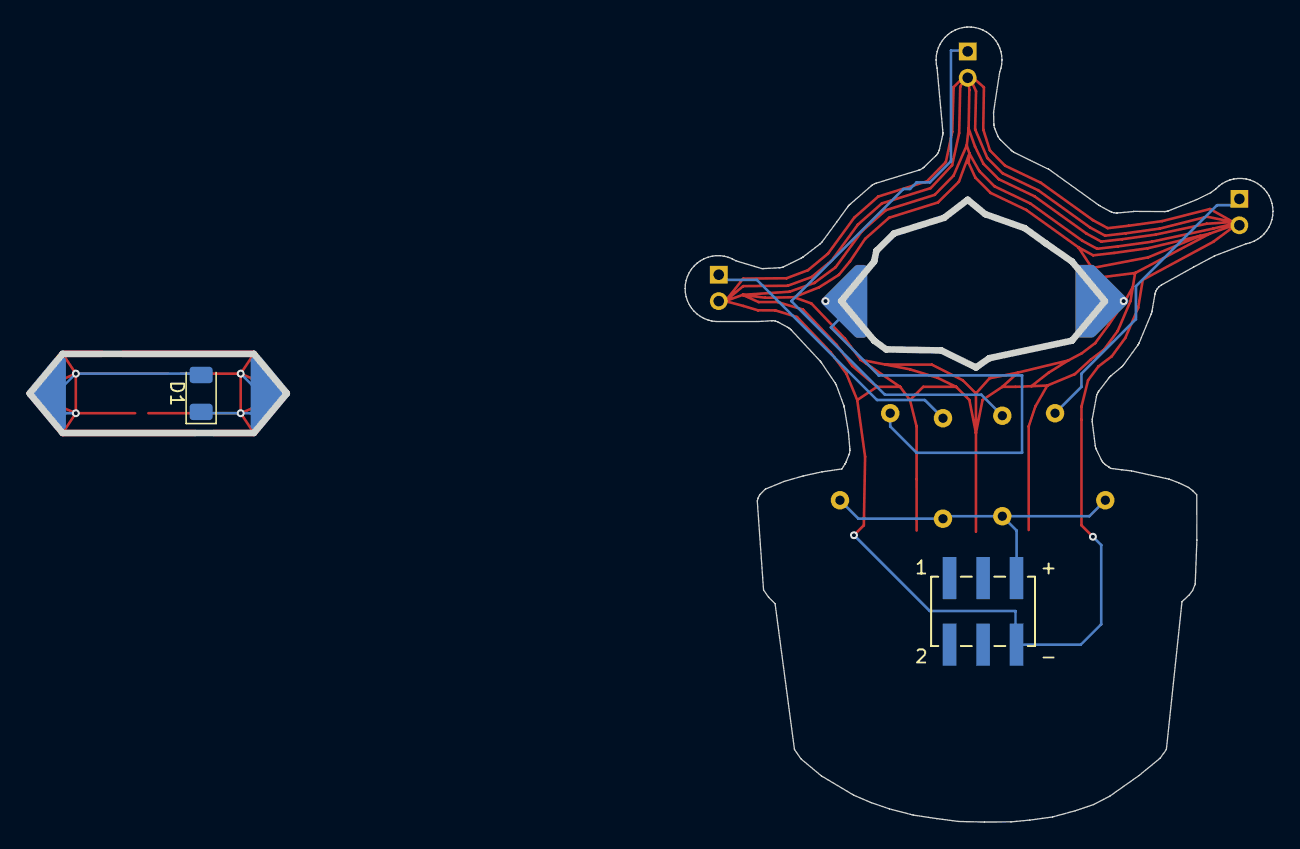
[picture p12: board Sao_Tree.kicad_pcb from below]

Board: 2 copper layers, 44.6 x 60.3 mm, 11 parts (2 on the bottom side), 6 nets.

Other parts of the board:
B1, B2: Board

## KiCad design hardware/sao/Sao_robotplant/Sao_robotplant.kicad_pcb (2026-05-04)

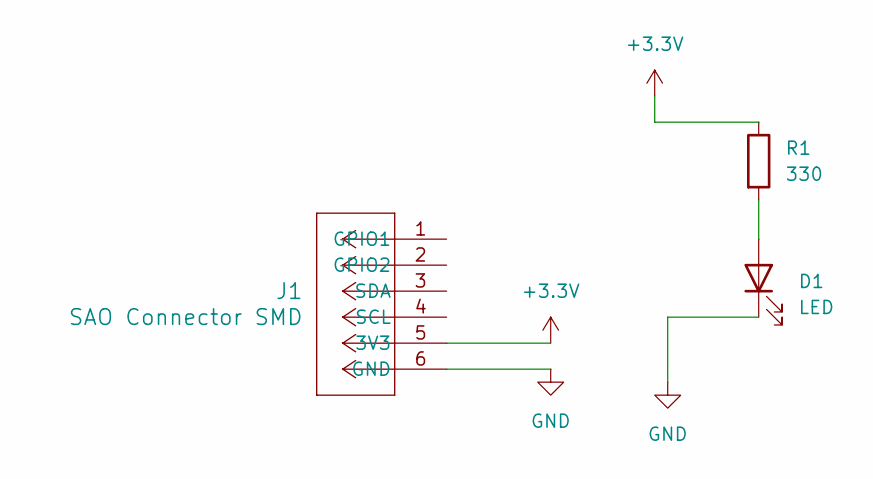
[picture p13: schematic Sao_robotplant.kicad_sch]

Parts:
D1: LED; LED_D3.0mm
J1: SAO Connector SMD
R1: 330; R_Axial_DIN0204_L3.6mm_D1.6mm_P7.62mm_Horizontal

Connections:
+3.3V: J1.5 (3V3), R1.1
GND: D1.1 (K), J1.6 (GND)
unnamed: D1.2 (A), R1.2

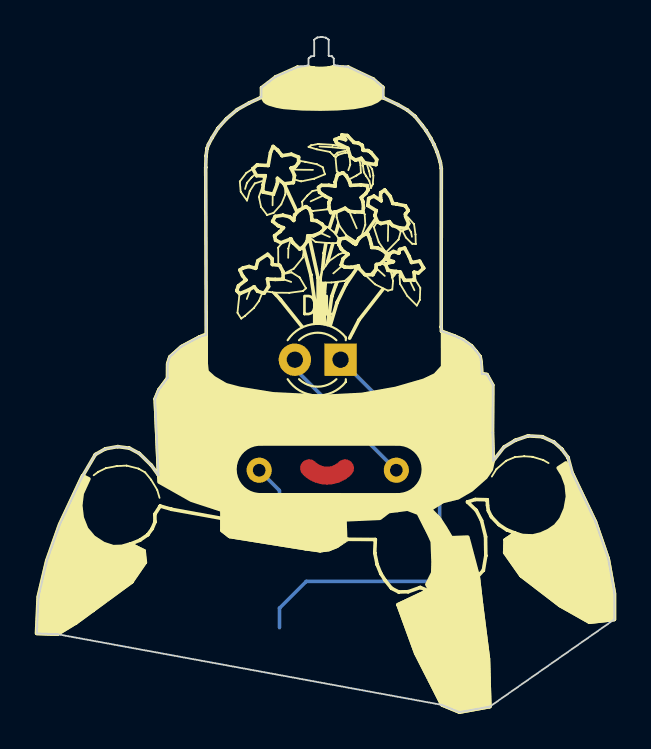
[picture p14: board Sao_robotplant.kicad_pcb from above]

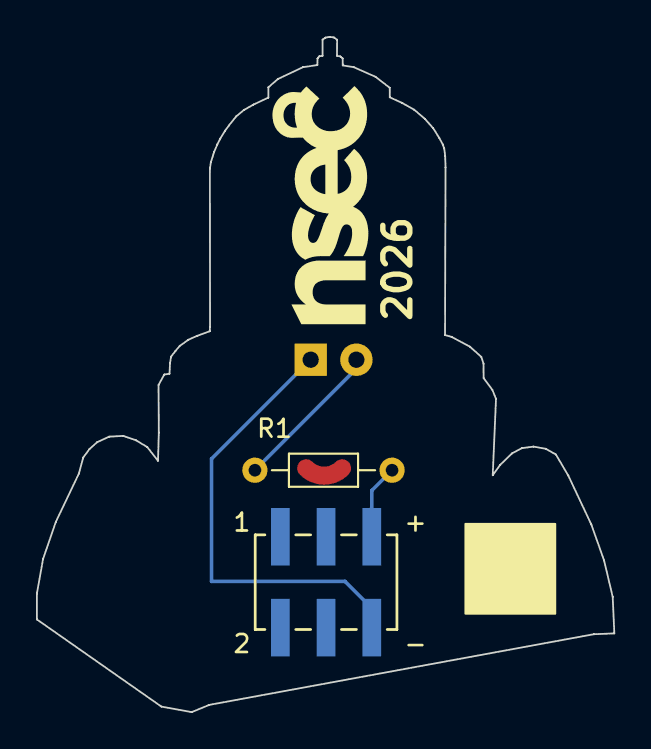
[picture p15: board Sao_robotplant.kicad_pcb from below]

Board: 2 copper layers, 32.1 x 37.5 mm, 3 parts (2 on the bottom side), 3 nets.

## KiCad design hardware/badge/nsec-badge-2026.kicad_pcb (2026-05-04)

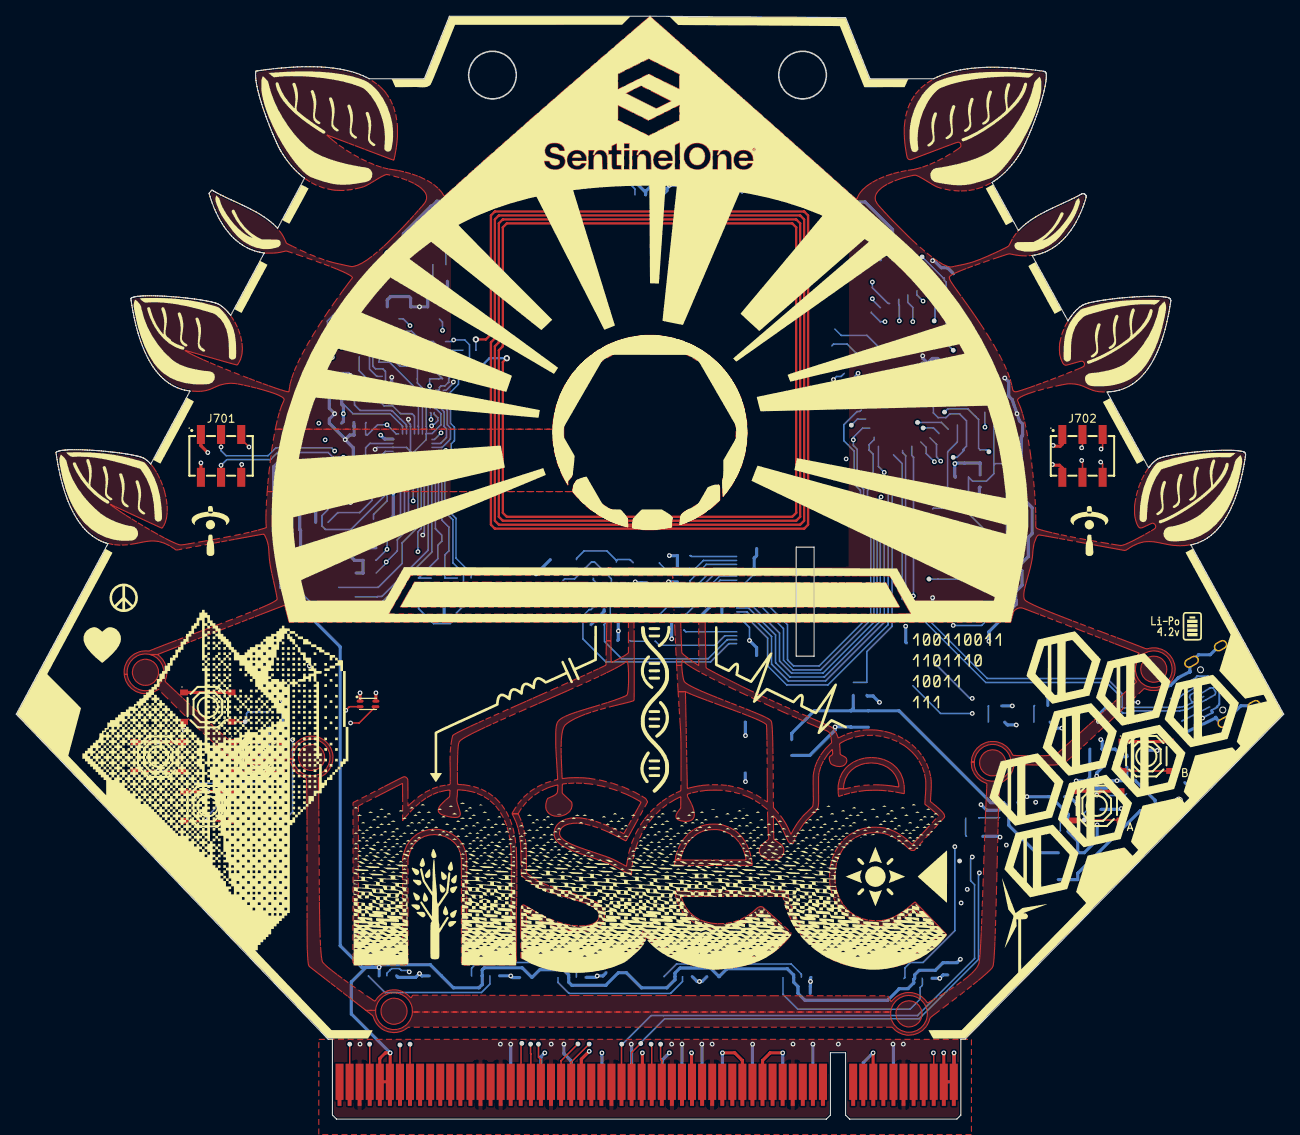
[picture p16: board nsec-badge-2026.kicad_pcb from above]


Board: 4 copper layers, 159.8 x 139.1 mm, 171 parts (161 on the bottom side), 106 nets.

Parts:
C201, C302: 10uF; C_0805_2012Metric
C202, C501, C502, C503, C504, C505, C506, C507, C508, C509, C510, C511, C512, C513, C514, C515, C516, C517, C518, C1101: 0.1uF; C_0603_1608Metric
C203, C301, C303, C1004, C1201, C1202, C1203, C1204, C1205, C1206, C1207, C1208, C1209, C1211: 1uF; C_0603_1608Metric
C801: 4.7uF; C_0805_2012Metric_Pad1.18x1.45mm_HandSolder
C802: 10uF; C_0805_2012Metric_Pad1.18x1.45mm_HandSolder
C803: 1uF; C_0805_2012Metric_Pad1.18x1.45mm_HandSolder
C1001, C1003, C1006, C1009, C1011, C1013, C1015, C1019: 10nF; C_0603_1608Metric
C1002, C1005, C1010, C1012, C1014, C1016: 2u2F; C_0603_1608Metric
C1007, C1008: 12pF; C_0603_1608Metric
C1017: 1nF; C_0603_1608Metric
C1018: 22nF; C_0603_1608Metric
C1020: 4u7F; C_0603_1608Metric
C1021, C1022: 680pF; C_0603_1608Metric
C1023, C1024: 33pF; C_0603_1608Metric
C1025, C1026, C1027: LXRW0YV600-054; X2SON-4_L0.6-W0.6-P0.40-BL
C1028, C1029: 150pF; C_0603_1608Metric
C1030, C1031: 47pF; C_0603_1608Metric
C1032, C1035: 10pF; C_0603_1608Metric
C1033, C1034: 220pF; C_0603_1608Metric
C1210, C1212: 4.7uF/50V; C_1206_3216Metric
D301, D302: MBR120LSF; SOD-123_L2.8-W1.8-LS3.7-RD
D1201, D1202, D1203: MBR0530; D_SOD-123
J701, J702: PM254-2-03-S-8_5; HDR-SMD_6P-P2.54-V-F-R2-C3-LS7.0
J901: Bus_PCI_32bit_Universal; BUS_PCI
J1001, J1002, J1003, J1004, J1005, J1006, J1007, J1008: Conn_01x01_Female; TestPoint_Pad_1.0x1.0mm
JP1201, JP1202: Jumper_2_Open; SolderJumper-2_P1.3mm_Open_RoundedPad1.0x1.5mm
KEY301: SSSS811101; SW-SMD_SSSS811101
L1001, L1002: MLJ1608WR27JT000; L_0603_1608Metric
L1201: 10uH; L_Vishay_IFSC-1515AH_4x4x1.8mm
LED201, LED301, LED302, LED801, LED1001: NCD0805R1; LED_0805_2012Metric_Pad1.15x1.40mm_HandSolder
P1001, P1002: U.FL-R-SMT-1_10_; U.FL_Hirose_U.FL-R-SMT-1_Vertical
Q1201: IRLML0100TRPBF; SOT-23-3
R201, R202, R204, R601, R602, R603, R604, R605, R606, R1201: 10K; R_0603_1608Metric
R203, R801, R802, R803, R1001: 1K; R_0603_1608Metric
R301, R303, R401, R402: 5.1K; R_0603_1608Metric
R302, R805: 100K; R_0603_1608Metric
R804: 390K; R_0603_1608Metric
R1002, R1003: 1k8 NF; R_0603_1608Metric
R1004, R1005: 1R5; R_0603_1608Metric
R1202: 0.47; R_0603_1608Metric
RGB501, RGB502, RGB503, RGB504, RGB505, RGB506, RGB507, RGB508, RGB509, RGB510, RGB511, RGB512, RGB513, RGB514, RGB515, RGB516, RGB517, RGB518: SK6812SIDE-A_C5378721; LED-SMD_SK6812SIDE-A_C5378721
SW201, SW202, SW601, SW602, SW603, SW604, SW605, SW606: TS-1187A-C-C-B; SW-SMD_4P-L5.1-W5.1-P3.70-LS6.5-TL_H1.5
TP201: UART_TX; TestPoint_Pad_D2.0mm
TP202: UART_RX; TestPoint_Pad_D2.0mm
TP203: GND; TestPoint_Pad_D2.0mm
U201: ESP32-S3-WROOM-1(N16R8); WIRELM-SMD_ESP32-S3-WROOM-1
U301: AP2112K-3_3TRG1; SOT-25-5_L2.9-W1.6-P0.95-LS2.8-BL
U401: TYPE-C-31-M-12; USB-C_SMD-TYPE-C-31-M-12
U402: TPSMF05CT1G; SOT-363_L2.0-W1.3-P0.65-LS2.1-BL
U801: XT4054K421MR-G; SOT-23-5_L3.0-W1.7-P0.95-LS2.8-BL
U802: XDWF-0920-02P; CONN-SMD_XDWF-0920-02P
U1001: ST25R3916-AQWT; QFN50P500X500X100-33N-D
U1101: VEML6040A3OG; SENSOR_SMD_VEML6040A3OG
U1202: HC-FPC-05-09-24RLTAG; FPC-SMD_24P-P0.50_HC-FPC-05-09-24RLTAG
Y1001: 27.12Mhz; Crystal_SMD_3225-4Pin_3.2x2.5mm

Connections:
+3V3: C201.1, C202.1, C302.1, C303.1, C1001.1, C1002.1, C1011.1, C1012.1, C1015.1, C1016.1, C1101.1, C1203.2, C1210.1, J701.1, J702.1, J901.A21 (+3.3V), J901.A27 (+3.3V), J901.A33 (+3.3V), J901.A39 (+3.3V), J901.A45 (+3.3V), J901.A53 (+3.3V), J901.B25 (+3.3V), J901.B31 (+3.3V), J901.B36 (+3.3V), J901.B41 (+3.3V), J901.B43 (+3.3V), J901.B54 (+3.3V), L1201.1, LED302.2 (A), R201.1, R202.1, R204.1, R601.1, R602.1, R603.1, R604.1, R605.1, R606.1, R1002.1, R1003.1, U201.2 (3V3), U301.5 (VOUT), U1001.1 (VDD_IO), U1001.8 (VDD), U1001.10 (VDD_TX), U1101.4 (VDD), U1202.15, U1202.16
/BTN_DOWN: J901.B4 (TDO), R602.2, SW602.3 (C), SW602.4 (D), U201.22 (IO14)
/BTN_UP: J901.B2 (TCK), R601.2, SW601.3 (C), SW601.4 (D), U201.21 (IO13)
/Battery Charger/CHRG: R801.2, U801.1 (CHRG#)
/Battery Charger/RPROG: R802.1, U801.5 (PROG)
/Battery Charger/VBAT_DIV: R804.2, R805.1, U201.4 (IO4)
/Buttons/BTN_A: R605.2, SW605.3 (C), SW605.4 (D), U201.10 (IO17)
/Buttons/BTN_B: R606.2, SW606.3 (C), SW606.4 (D), U201.11 (IO18)
/Buttons/BTN_LEFT: R603.2, SW603.3 (C), SW603.4 (D), U201.8 (IO15)
/Buttons/BTN_RIGHT: R604.2, SW604.3 (C), SW604.4 (D), U201.9 (IO16)
/ESP32-S3/BOOTSEL: J901.B30 (AD[19]), SW202.3 (C), SW202.4 (D), U201.27 (IO0)
/ESP32-S3/GPIO12: U201.20 (IO12), U1001.29 (BSS)
/ESP32-S3/GPIO21: U201.23 (IO21), U1001.27 (IRQ)
/ESP32-S3/GPIO38: J901.B7 (~INTB#), U201.31 (IO38)
/ESP32-S3/GPIO39: J901.B8 (~INTD#), U201.32 (IO39)
/ESP32-S3/GPIO40: R1001.1, U201.33 (IO40)
/ESP32-S3/GPIO41: U201.34 (IO41), U1202.12
/ESP32-S3/GPIO42: U201.35 (IO42), U1202.11
/ESP32-S3/GPIO45: U201.26 (IO45), U1202.10
/ESP32-S3/GPIO46: U201.16 (IO46), U1202.9
/ESP32-S3/MCU_LED: LED201.2 (A), U201.7 (IO7)
/ESP32-S3/RESET: C203.1, J901.B29 (AD[21]), R204.2, SW201.3 (C), SW201.4 (D), U201.3 (EN)
/ESP32-S3/RGB_LED: RGB501.1 (DIN), U201.12 (IO8)
/ESP32-S3/UART_RX: J901.B24 (AD[25]), TP202.1, U201.36 (RXD0)
/ESP32-S3/UART_TX: J901.B23 (AD[27]), TP201.1, U201.37 (TXD0)
/ESP32-S3/USB_D+: U201.14 (IO20), U401.A6 (DP1), U401.B6 (DP2), U402.6
/ESP32-S3/USB_D-: U201.13 (IO19), U401.A7 (DN1), U401.B7 (DN2), U402.5
/GPIO1: J701.3, J702.3, J901.B19 (VIO), U201.39 (IO1)
/GPIO2: J701.4, J702.4, J901.B20 (AD[31]), U201.38 (IO2)
/GPIO3: J901.B21 (AD[29]), U201.15 (IO3)
/I2C_SCL: J701.5, J702.5, J901.B33 (~C/BE#[2]), R202.2, U201.6 (IO6), U1101.3 (SCL)
/I2C_SDA: J701.2, J702.2, J901.B32 (AD[17]), R201.2, U201.5 (IO5), U1101.2 (SDA)
/NFC/AAT_P: C1027.2 (VT), P1002.1 (In), U1001.19 (AAT_B)
/NFC/AAT_S: C1025.2 (VT), C1026.2 (VT), P1001.1 (In), U1001.18 (AAT_A)
/NFC/AGDC: C1004.1, C1006.1, U1001.24 (AGDC)
/NFC/EXT_LM: J1004.1, U1001.17 (EXT_LM)
/NFC/NFC_COIL: R1004.2, R1005.2
/NFC/RFI1: C1032.2, C1033.1, J1008.1, U1001.22 (RFI1)
/NFC/RFI2: C1034.2, C1035.1, J1007.1, U1001.23 (RFI2)
/NFC/RFO1: J1006.1, L1001.1, U1001.13 (RFO1)
/NFC/RFO2: J1005.1, L1002.1, U1001.15 (RFO2)
/NFC/VDD_A: C1009.1, C1010.1, U1001.7 (VDD_A)
/NFC/VDD_AM: C1017.1, C1018.1, U1001.11 (VDD_AM)
/NFC/VDD_D: C1003.1, C1005.1, U1001.3 (VDD_D)
/NFC/VDD_DR: C1013.1, C1014.1, C1019.1, C1020.1, U1001.9 (VDD_RF), U1001.14 (VDD_DR)
/Power Regulator/POWER_IN: D301.1 (C), D302.1 (C), KEY301.3
/RGB_END: J901.B60 (~ACK64#), RGB518.3 (DOUT)
/SPI_MISO: R1002.2, U201.18 (IO10), U1001.32 (MISO/SDA)
/SPI_MOSI: U201.19 (IO11), U1001.31 (MOSI), U1202.14
/SPI_SCK: R1003.2, U201.17 (IO9), U1001.30 (SCLK/SCL), U1202.13
/e-ink display/GDR: Q1201.1 (G), R1201.2, U1202.2
/e-ink display/PREVGH: C1211.1, D1201.1 (K), U1202.21
/e-ink display/PREVGL: C1208.2, D1203.2 (A), U1202.23
/e-ink display/RESE: Q1201.2 (S), R1202.2, U1202.3
/e-ink display/VCOM: C1209.2, U1202.24
/e-ink display/VDD: C1204.2, U1202.18
/e-ink display/VGH: C1202.2, U1202.5
/e-ink display/VGL: JP1201.2 (B), U1202.4
/e-ink display/VSH: C1206.2, U1202.20
/e-ink display/VSL: C1207.2, U1202.22
GND: C201.2, C202.2, C203.2, C301.2, C302.2, C303.2, C501.2, C502.2, C503.2, C504.2, C505.2, C506.2, C507.2, C508.2, C509.2, C510.2, C511.2, C512.2, C513.2, C514.2, C515.2, C516.2, C517.2, C518.2, C801.2, C802.2, C803.2, C1001.2, C1002.2, C1003.2, C1004.2, C1005.2, C1006.2, C1007.2, C1008.2, C1009.2, C1010.2, C1011.2, C1012.2, C1013.2, C1014.2, C1015.2, C1016.2, C1017.2, C1018.2, C1019.2, C1020.2, C1021.2, C1022.1, C1025.1 (G), C1026.1 (G), C1027.1 (G), C1030.2, C1031.1, C1033.2, C1034.1, C1101.2, C1201.1, C1202.1, C1203.1, C1204.1, C1205.1, C1206.1, C1207.1, C1208.1, C1209.1, C1210.2, C1211.2, D1202.1 (K), J701.6, J702.6, J901.A18 (GND), J901.A24 (GND), J901.A30 (GND), J901.A35 (GND), J901.A37 (GND), J901.A42 (GND), J901.A48 (GND), J901.A56 (GND), J901.B3 (GND), J901.B15 (GND), J901.B17 (GND), J901.B22 (GND), J901.B28 (GND), J901.B34 (GND), J901.B38 (GND), J901.B46 (GND), J901.B57 (GND), KEY301.4, KEY301.5, KEY301.6, KEY301.7, LED1001.1 (K), P1001.2 (Ext), P1002.2 (Ext), R203.2, R301.2, R303.2, R401.2, R402.2, R803.2, R805.2, R1201.1, R1202.1, RGB501.4 (GND), RGB502.4 (GND), RGB503.4 (GND), RGB504.4 (GND), RGB505.4 (GND), RGB506.4 (GND), RGB507.4 (GND), RGB508.4 (GND), RGB509.4 (GND), RGB510.4 (GND), RGB511.4 (GND), RGB512.4 (GND), RGB513.4 (GND), RGB514.4 (GND), RGB515.4 (GND), RGB516.4 (GND), RGB517.4 (GND), RGB518.4 (GND), SW201.1 (A), SW201.2 (B), SW202.1 (A), SW202.2 (B), SW601.1 (A), SW601.2 (B), SW602.1 (A), SW602.2 (B), SW603.1 (A), SW603.2 (B), SW604.1 (A), SW604.2 (B), SW605.1 (A), SW605.2 (B), SW606.1 (A), SW606.2 (B), TP203.1, U201.1 (GND), U201.40 (GND), U201.41 (GND), U301.2 (GND), U401.0 (SH), U401.1 (SH), U401.2 (SH), U401.3 (SH), U401.A1 (GND), U401.A12 (GND), U401.B1 (GND), U401.B12 (GND), U402.2, U801.2 (GND), U802.1, U802.3, U802.4, U1001.6 (GND_D), U1001.12 (GND_DR_1), U1001.16 (GND_DR_2), U1001.20 (I2C_EN), U1001.21 (VSS), U1001.26 (GND_A), U1001.33 (EP), U1101.1 (GND), U1202.8, U1202.17, U1202.25, U1202.26, Y1001.2, Y1001.4
unnamed: C1023.1, C1025.3 (Pt1), C1028.1, C1030.1, C1032.1, R1004.1
unnamed: C1021.1, C1023.2, C1025.4 (Pt2), L1001.2
unnamed: C1022.2, C1024.1, C1026.3 (Pt1), L1002.2
unnamed: C1024.2, C1026.4 (Pt2), C1029.2, C1031.2, C1035.2, R1005.1
unnamed: C1027.3 (Pt1), C1029.1
unnamed: C1027.4 (Pt2), C1028.2
unnamed: C1212.1, D1201.2 (A), L1201.2, Q1201.3 (D)
unnamed: C1212.2, D1202.2 (A), D1203.1 (K)
unnamed: C1201.2, JP1201.1 (A)
unnamed: C1205.2, JP1202.1 (A)
unnamed: JP1202.2 (B), U1202.19
unnamed: LED201.1 (K), R203.1
unnamed: LED301.1 (K), R301.1
unnamed: LED302.1 (K), R303.1
unnamed: LED801.1 (K), R801.1
unnamed: LED1001.2 (A), R1001.2
unnamed: R802.2, R803.1
unnamed: RGB501.3 (DOUT), RGB502.1 (DIN)
unnamed: RGB502.3 (DOUT), RGB503.1 (DIN)
unnamed: RGB503.3 (DOUT), RGB504.1 (DIN)
unnamed: RGB504.3 (DOUT), RGB505.1 (DIN)
unnamed: RGB505.3 (DOUT), RGB506.1 (DIN)
unnamed: RGB506.3 (DOUT), RGB507.1 (DIN)
unnamed: RGB507.3 (DOUT), RGB508.1 (DIN)
unnamed: RGB508.3 (DOUT), RGB509.1 (DIN)
unnamed: RGB509.3 (DOUT), RGB510.1 (DIN)
unnamed: RGB510.3 (DOUT), RGB511.1 (DIN)
unnamed: RGB511.3 (DOUT), RGB512.1 (DIN)
unnamed: RGB512.3 (DOUT), RGB513.1 (DIN)
unnamed: RGB513.3 (DOUT), RGB514.1 (DIN)
unnamed: RGB514.3 (DOUT), RGB515.1 (DIN)
unnamed: RGB515.3 (DOUT), RGB516.1 (DIN)
unnamed: RGB516.3 (DOUT), RGB517.1 (DIN)
unnamed: RGB517.3 (DOUT), RGB518.1 (DIN)
unnamed: R302.2, U301.3 (EN)
unnamed: R402.1, U401.A5 (CC1)
unnamed: R401.1, U401.B5 (CC2)
unnamed: J1002.1, U1001.28 (MCU_CLK)
unnamed: J1001.1, U1001.25 (TAD1)
unnamed: J1003.1, U1001.2 (TAD2)
unnamed: C1008.1, U1001.5 (XTI), Y1001.3
unnamed: C1007.1, U1001.4 (XTO), Y1001.1
VBAT: C802.1, C803.1, D301.2 (A), R804.1, U801.3 (BAT), U802.2
VBUS: C801.1, D302.2 (A), LED801.2 (A), U401.A4 (VBUS), U401.A9 (VBUS), U401.B4 (VBUS), U401.B9 (VBUS), U402.4, U801.4 (VCC)
VDD: C301.1, C501.1, C502.1, C503.1, C504.1, C505.1, C506.1, C507.1, C508.1, C509.1, C510.1, C511.1, C512.1, C513.1, C514.1, C515.1, C516.1, C517.1, C518.1, J901.A5 (+5V), J901.A8 (+5V), J901.A61 (+5V), J901.A62 (+5V), J901.B5 (+5V), J901.B6 (+5V), J901.B61 (+5V), J901.B62 (+5V), KEY301.2, LED301.2 (A), R302.1, RGB501.2 (VDD), RGB502.2 (VDD), RGB503.2 (VDD), RGB504.2 (VDD), RGB505.2 (VDD), RGB506.2 (VDD), RGB507.2 (VDD), RGB508.2 (VDD), RGB509.2 (VDD), RGB510.2 (VDD), RGB511.2 (VDD), RGB512.2 (VDD), RGB513.2 (VDD), RGB514.2 (VDD), RGB515.2 (VDD), RGB516.2 (VDD), RGB517.2 (VDD), RGB518.2 (VDD), U301.1 (VIN)

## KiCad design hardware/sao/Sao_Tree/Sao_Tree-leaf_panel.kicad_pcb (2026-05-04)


Board: 2 copper layers, 37.0 x 73.0 mm, 73 parts (0 on the bottom side), 6 nets.

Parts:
D1: LED; LED_1206_3216Metric
D2: LED; LED_D5.0mm
D3: LED; LED_0805_2012Metric
J2, J5, J6: Conn_01x02_Socket; PinSocket_1x02_P2.00mm_Vertical
KiKit_MB_1_2, KiKit_MB_1_3, KiKit_MB_1_4, KiKit_MB_1_5, KiKit_MB_1_6, KiKit_MB_1_7, KiKit_MB_2_2, KiKit_MB_2_3, KiKit_MB_2_4, KiKit_MB_2_5, KiKit_MB_2_6, KiKit_MB_2_7, KiKit_MB_3_2, KiKit_MB_3_3, KiKit_MB_3_4, KiKit_MB_3_5, KiKit_MB_3_6, KiKit_MB_3_7, KiKit_MB_4_2, KiKit_MB_4_3, KiKit_MB_4_4, KiKit_MB_4_5, KiKit_MB_4_6, KiKit_MB_4_7, KiKit_MB_5_2, KiKit_MB_5_3, KiKit_MB_5_4, KiKit_MB_5_5, KiKit_MB_5_6, KiKit_MB_5_7, KiKit_MB_6_2, KiKit_MB_6_3, KiKit_MB_6_4, KiKit_MB_6_5, KiKit_MB_6_6, KiKit_MB_6_7, KiKit_MB_7_2, KiKit_MB_7_3, KiKit_MB_7_4, KiKit_MB_7_5, KiKit_MB_7_6, KiKit_MB_7_7, KiKit_MB_8_2, KiKit_MB_8_3, KiKit_MB_8_4, KiKit_MB_8_5, KiKit_MB_8_6, KiKit_MB_8_7, KiKit_MB_9_2, KiKit_MB_9_3, KiKit_MB_9_4, KiKit_MB_10_2, KiKit_MB_10_3, KiKit_MB_10_4, KiKit_MB_10_5, KiKit_MB_11_2, KiKit_MB_11_3, KiKit_MB_11_4, KiKit_MB_12_2, KiKit_MB_12_3, KiKit_MB_12_4, KiKit_MB_13_3, KiKit_MB_13_4, KiKit_MB_13_5, KiKit_MB_14_2, KiKit_MB_14_3, KiKit_MB_14_4: NPTH

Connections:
Board_0-+3.3V: D1.2 (A), J5.1
Board_0-GND: D1.1 (K), J5.2
Board_1-+3.3V: D3.2 (A), J2.1
Board_1-GND: D3.1 (K), J2.2
Board_2-+3.3V: D2.2 (A), J6.1
Board_2-GND: D2.1 (K), J6.2

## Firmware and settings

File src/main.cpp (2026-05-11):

/*
 * NorthSec Badge 2026 Firmware (ESP32-S3)
 * PlatformIO + Arduino (no .ino)
 *
 * SPDX-License-Identifier: Apache-2.0
 */

#include <Arduino.h>

#include <cstring>

#include <badge_config.h>
#include <core.h>
#include <animation/parser.h>
#include <animation/storage.h>
#include <hardware/line_buffered_stream.h>
#include <hardware/light_sensor.h>
#include <hardware/serial_mutex.h>

// Conditionally include conference or challenges based on build flags
#ifdef HAS_CONFERENCE
  #include <../lib/conference/registry.h>
#endif

#ifdef HAS_CHALLENGES
  #include <../lib/challenges/registry.h>

// Simple obfuscation of a cleartext string to get past the CICD check.
const std::string cleartextFirmwareFlg =
    "\x46\x4c\x41\x47\x2d\x69\x2d\x63\x34\x6e\x2d\x68\x34\x7a\x2d\x66\x31\x72\x6d\x77\x34\x72\x33";
#endif

void setup() {
  Serial.setTxBufferSize(4096);
#ifndef NATIVE_BUILD
  Serial.setRxBufferSize(4096);
#endif
  Serial.begin(115200);

  // Send test pattern
  for (int i = 0; i < 10; i++) {
    Serial.println();
  }

  Serial.println("=========================");
  Serial.println("NorthSec Badge 2026");
  Serial.println("BOOT SUCCESSFUL!");
  Serial.print("Build: ");
  Serial.print(__DATE__);
  Serial.print(" ");
  Serial.println(__TIME__);
#ifdef CONFERENCE_ONLY
  Serial.println("Mode:  conference-only");
#elif defined(HAS_CHALLENGES)
  Serial.println("Mode:  ctf");
#elif defined(HAS_CONFERENCE)
  Serial.println("Mode:  conference (dual)");
#endif
  Serial.println("=========================");
  Serial.flush();

  core::hw::statusLedInit();
  core::hw::rgbInit();
  core::hw::buttonsInit();
  // Serial.println("LEDs initialized");

  core::storage::socialNvsInit();
  core::storage::configNvsInit();

  if (core::animation::storageInit()) {
    Serial.println("Animation filesystem initialized");
  } else {
    Serial.println("WARNING: Animation filesystem init failed");
  }

  if (core::hw::nfcInit()) {
    Serial.println("NFC initialized");
  } else {
    Serial.println("NFC init failed - NFC features disabled");
  }

  // Create dock event queue BEFORE dockInit so the I2C ISR has
  // a valid queue handle from the moment callbacks are registered.
  static core::Queue<core::DockEvent> dockEventQueue(badge::config::queues::dock_depth);
  core::hw::dockSetEventQueue(dockEventQueue.handle());

  core::hw::dockInit();

  if (core::hw::einkInit()) {
    Serial.println("E-Ink initialized");
  } else {
    Serial.println("E-Ink init failed - display features disabled");
  }

  // Light sensor shares the same I2C pins as the dock. Each read temporarily
  // borrows the bus (Wire1 master) then restores the dock slave (Wire).
  if (core::hw::lightSensorInit()) {
    Serial.println("Light sensor initialized");
  } else {
    Serial.println("Light sensor init failed");
  }

  core::ota::printBootInfo(Serial);

  static core::hw::LineBufferedStream bufferedSerial(Serial);
  core::hw::setSafeSerial(&bufferedSerial);
  core::cli::init(bufferedSerial);

#ifdef HAS_CONFERENCE
  conference::init();
  Serial.println("Conference modules initialized");
#endif

#ifdef HAS_CHALLENGES
  challenges::init();
  Serial.println("Challenges initialized");
#endif

  // Apply saved brightness
  {
    auto cfg = core::storage::configRead();
    core::hw::rgbSetBrightness(cfg.brightness);
  }

  // Create queues
  static core::Queue<core::ControllerEvent> controllerQueue(badge::config::queues::controller_depth);
  static core::Queue<core::LedCommand> ledQueue(badge::config::queues::led_depth);
  static core::Queue<core::CliResponse> cliQueue(badge::config::queues::cli_depth);
  static core::Queue<core::NfcCommand> nfcQueue(badge::config::queues::nfc_depth);
  static core::Queue<core::DisplayCommand> displayQueue(badge::config::queues::display_depth);
  static core::Queue<core::PortalCommand> portalQueue(badge::config::queues::portal_depth);

  core::g_controllerQueue = &controllerQueue;
  core::g_ledQueue = &ledQueue;
  core::g_cliQueue = &cliQueue;
  core::g_nfcQueue = &nfcQueue;
  core::g_displayQueue = &displayQueue;

  // Create tasks
  static core::LedTask ledTask(ledQueue);
  static core::ControllerTask controllerTask(controllerQueue, ledQueue, cliQueue, nfcQueue, displayQueue, portalQueue);
  static core::CliTask cliTask;
  static core::ButtonTask buttonTask(controllerQueue);
  static core::NfcTask nfcTask(nfcQueue, controllerQueue, displayQueue);
  static core::DockTask dockTask(dockEventQueue, ledQueue);
  static core::DisplayTask displayTask(displayQueue);
  static core::LightTask lightTask;
  static core::PortalTask portalTask(portalQueue, controllerQueue);

  core::heartbeatStart();

  // Print boot-complete banner before starting tasks so it is never
  // interleaved with asynchronous task output.
  Serial.println("Setup complete!");
  Serial.println("Type 'help' for commands.");
  Serial.flush();

  ledTask.start();
  controllerTask.start();
  cliTask.start();
  buttonTask.start();
  nfcTask.start();
  dockTask.start();
  displayTask.start();
  portalTask.start();

  // Show boot logo on the e-ink early so it's visible before the
  // controller task's first frame. The controller will re-issue it on
  // enterIdle but the duplicate is harmless.
  {
    core::DisplayCommand dc{};
    dc.type = core::DisplayCommand::Type::ShowLogo;
    displayQueue.send(dc, core::Milliseconds(0));
  }

  lightTask.start();
}

void loop() {
  vTaskDelay(portMAX_DELAY);
}

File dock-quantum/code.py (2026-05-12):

"""
NSec Badge Dock - Quantum Challenge Track (2026)
CircuitPython 9.2.x on ESP32-S3 DevKitC

Validates both Crystal Tuning (VQE) and Grid Optimization (QAOA) challenges.

Protocol:
  1. Dock detects badge at I2C address 0x68
  2. Dock requests CrystalState blob  [0x10, 0x03],  reads 42 bytes
  3. Dock requests GridState blob     [0x10, 0x04],  reads 24 bytes
  4. Dock independently recomputes expected energy from badge params
  5. Dock sends validation results + flags back to badge
  6. Dock sends LED color feedback

Validation model:
  - Badge stores canonicalized solve artifacts (params in milliradians, energy, CRC-32)
  - Dock recomputes energy from params using identical Hamiltonian (same PRNG seed)
  - Dock compares recomputed energy against badge-reported energy
  - Dock verifies energy is below solve threshold
  - Only then is the flag issued
"""

import board
import busio
import time
import math
import struct
import neopixel
import digitalio
import supervisor

# --- Pin Configuration (same as social dock) ---
PIN_NEOPIXEL = board.IO48
PIN_I2C_SCL = board.IO5
PIN_I2C_SDA = board.IO4
PIN_DETECT_OUT1 = board.IO9
PIN_DETECT_IN = board.IO10
PIN_DETECT_OUT2 = board.IO11

# --- Constants ---
BADGE_I2C_ADDR = 0x68

CMD_REQUEST_HWID = 0x01
CMD_SET_LED_COLOR = 0x02
CMD_CHALLENGE_DATA = 0x10

# Sub-opcodes (must match badge quantum.cpp)
CRYSTAL_REQUEST = 0x03
CRYSTAL_RESULT = 0x05
GRID_REQUEST = 0x04
GRID_RESULT = 0x06

LED_OFF = 0x00
LED_RED = 0x01
LED_GREEN = 0x02
LED_BLUE = 0x03

# --- Flags ---
CRYSTAL_FLAG = "FLAG{cryst4l_tun3d_VQE_2026}"
GRID_FLAG = "FLAG{gr1d_0pt1m1z3d_QAOA_2026}"

# --- Colors ---
RED = (255, 0, 0)
GREEN = (0, 255, 0)
BLUE = (0, 0, 255)
PURPLE = (128, 0, 255)
CYAN = (0, 255, 255)
YELLOW = (255, 255, 0)
OFF = (0, 0, 0)
WHITE = (255, 255, 255)

# ===========================================================================
# Quantum simulation (pure Python, matches badge qsim.cpp exactly)
# ===========================================================================

def xorshift32(seed):
    """Same PRNG as badge coeff_rng / qsim xorshift32."""
    seed &= 0xFFFFFFFF
    seed ^= (seed << 13) & 0xFFFFFFFF
    seed ^= (seed >> 17)
    seed ^= (seed << 5) & 0xFFFFFFFF
    return seed & 0xFFFFFFFF

def rng_float(seed, lo, hi):
    seed = xorshift32(seed)
    u = seed / 4294967296.0
    return seed, lo + u * (hi - lo)

# ---------------------------------------------------------------------------
# Crystal Hamiltonian — TFIM chain (must match crystal.cpp)
# ---------------------------------------------------------------------------
NUM_CRYSTAL_QUBITS = 8
NUM_CRYSTAL_LAYERS = 2
NUM_CRYSTAL_PARAMS = 16

def build_crystal_hamiltonian():
    seed = 0x4E534543  # "NSEC"
    J = 1.0
    h = 1.5
    delta = []
    for _ in range(NUM_CRYSTAL_QUBITS):
        seed, v = rng_float(seed, -0.15, 0.15)
        delta.append(v)
    return J, h, delta

def crystal_evaluate(params_rad, J, h, delta):
    """Pure-Python TFIM VQE evaluation matching badge crystal.cpp."""
    nq = NUM_CRYSTAL_QUBITS
    dim = 1 << nq
    sv = [complex(0, 0)] * dim
    sv[0] = complex(1, 0)

    def gate_ry(sv, q, theta):
        co = math.cos(theta / 2)
        si = math.sin(theta / 2)
        mask = 1 << q
        for i in range(dim):
            if i & mask:
                continue
            i0, i1 = i, i | mask
            v0, v1 = sv[i0], sv[i1]
            sv[i0] = co * v0 - si * v1
            sv[i1] = si * v0 + co * v1

    def gate_cz(sv, q0, q1):
        m0, m1 = 1 << q0, 1 << q1
        for i in range(dim):
            if (i & m0) and (i & m1):
                sv[i] = -sv[i]

    # Ansatz: 2 layers of [RY per qubit, CZ chain]
    for layer in range(NUM_CRYSTAL_LAYERS):
        for q in range(nq):
            gate_ry(sv, q, params_rad[layer * nq + q])
        for q in range(nq - 1):  # chain, not ring
            gate_cz(sv, q, q + 1)

    def expect_z(q):
        val = 0.0
        mask = 1 << q
        for i in range(dim):
            p = abs(sv[i]) ** 2
            val += -p if (i & mask) else p
        return val

    def expect_zz(q0, q1):
        val = 0.0
        m0, m1 = 1 << q0, 1 << q1
        for i in range(dim):
            p = abs(sv[i]) ** 2
            par = ((1 if (i & m0) else 0) ^ (1 if (i & m1) else 0))
            val += -p if par else p
        return val

    def expect_x(q):
        val = 0.0
        mask = 1 << q
        for i in range(dim):
            if i & mask:
                continue
            i0, i1 = i, i | mask
            val += 2.0 * (sv[i0].real * sv[i1].real + sv[i0].imag * sv[i1].imag)
        return val

    energy = 0.0
    # -J Σ ZZ chain
    for i in range(nq - 1):
        energy -= J * expect_zz(i, i + 1)
    # -h Σ X
    for i in range(nq):
        energy -= h * expect_x(i)
    # Σ δᵢ Z
    for i in range(nq):
        energy += delta[i] * expect_z(i)
    return energy

def crystal_threshold(J, h, delta):
    nq = NUM_CRYSTAL_QUBITS
    bound = (nq - 1) * abs(J) + nq * abs(h) + sum(abs(d) for d in delta)
    return (-bound) * 0.642

# ---------------------------------------------------------------------------
# Grid Hamiltonian (must match grid.cpp with seed 0x47524944)
# ---------------------------------------------------------------------------
NUM_GRID_QUBITS = 10
NUM_GRID_SAMPLES = 256
GRID_SAMPLE_SEED = 0xDEADBEEF

def build_grid_hamiltonian():
    seed = 0x47524944  # "GRID"
    nq = NUM_GRID_QUBITS
    h = []
    for _ in range(nq):
        seed, v = rng_float(seed, -1.0, 1.0)
        h.append(v)

    edges = []
    J = {}
    # Ring
    for i in range(nq):
        j = (i + 1) % nq
        seed, w = rng_float(seed, -1.0, 1.0)
        J[(i, j)] = w
        edges.append((i, j, w))

    # 5 random extra edges
    for _ in range(5):
        seed = xorshift32(seed)
        i = seed % nq
        seed = xorshift32(seed)
        j = seed % nq
        if i == j:
            j = (j + 1) % nq
        if i > j:
            i, j = j, i
        if (i, j) not in J:
            seed, w = rng_float(seed, -0.5, 0.5)
            J[(i, j)] = w
            edges.append((i, j, w))

    # Precompute diagonal costs
    dim = 1 << nq
    diag = [0.0] * dim
    for z in range(dim):
        c = 0.0
        for qi in range(nq):
            si = -1.0 if (z & (1 << qi)) else 1.0
            c += h[qi] * si
        for (ei, ej, ew) in edges:
            si = -1.0 if (z & (1 << ei)) else 1.0
            sj = -1.0 if (z & (1 << ej)) else 1.0
            c += ew * si * sj
        diag[z] = c

    return h, edges, diag
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

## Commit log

2025-12-14 Initial scaffold in place
    [badge_factory_ota.csv]
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2026-01-03 Switched to local broker, fix connection logic
2026-02-08 working renamed partitions
    [badge_factory_ota.csv]
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2026-02-22 Proto v1 Kicad Files
    [BOM-nsec-badge-2026.csv, SAO_Female.kicad_sch, battery_charger.kicad_sch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]
2026-02-22 cli: use std::string instead of Arduino String
    Replace Arduino's String class with std::string throughout the CLI
    module and its users. This change prepares the codebase for
    cross-platform compilation by removing the dependency on Arduino's
    WString implementation.
    Changes:
    - Update CommandHandler typedef to use std::string
    - Replace String methods with std::string equivalents:
    - substring(start, end) -> substr(start, length)
    - toLowerCase() -> custom toLower() helper
    - trim() -> custom trim() helper
    - remove() -> pop_back()
    - Add toLower() and trim() helper functions using standard library
    - Update lambda signatures in schedule.cpp and crypto.cpp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
2026-02-22 simulator: add Arduino and ESP-IDF API stubs
    Add a simulator library providing stub implementations of Arduino and
    ESP-IDF APIs for desktop/native builds. This allows the badge firmware
    to compile and run on a development machine for testing and debugging.
    Arduino stubs (lib/simulator/arduino/):
    - Arduino.h: Core types, GPIO functions, timing (millis/delay via
    std::chrono), character classification functions
    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
2026-02-22 build: add native simulator environment with FreeRTOS POSIX port
    Add a PlatformIO native build environment that allows the badge firmware
    to run on a desktop machine. The simulator uses the FreeRTOS POSIX port
    to provide real task scheduling via pthreads.
    FreeRTOS integration:
    - Add FreeRTOS-Kernel as a git submodule (extern/FreeRTOS-Kernel)
    - Add FreeRTOSConfig.h configured for the POSIX/Linux port
    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
2026-03-01 core: reorganize into tasks/, rtos/, and include/
    Add event types and heartbeat timer. CLI and heartbeat live under
    tasks/, per-task headers hold their queue and command types, and
    config constants go in include/badge_config.h. rtos/ only holds
    the Task and Queue FreeRTOS wrappers.
2026-03-01 tasks: activate heartbeat timer
    Replace the manual heartbeat toggle in loop() with the FreeRTOS
    software timer (core::heartbeatStart()) called from setup().
    I didn't see a ~500ms blinking LED on the badge before my
    changes, so I'm assuming the core::hw::statusLedSet function
    may not be doing the right thing at the moment.
    [main.cpp]
2026-03-01 tasks: redefine message types for task-based architecture
    Rewrite ControllerEvent with a progress function pointer for CLI
    feedback. Flatten LedCommandType to one enum value per animation.
    Add CliResponse type and cli_depth queue config constant.
2026-03-01 led: extract animations into LED task module
    Move animation implementations (solidColor, pixelWalk, rainbow, off)
    from cli.cpp into led_task.h/cpp. The CLI's cmdLedTest() now calls
    these functions directly and uses animationName() for progress output.
    LedTask::run() dispatches LedCommands to the same animation functions.
2026-03-01 tasks: add controller and CLI tasks
    Define ControllerTask (dispatches ControllerEvents, orchestrates LED
    test sequence via LedCommand queue, sends CliResponse on completion)
    and CliTask (wraps cli::poll() in a FreeRTOS task loop). Task classes
    are defined but not yet instantiated.
2026-03-01 main: assemble and start task-based system
    setup() creates three queues (controller, LED, CLI) and three tasks
    (CliTask, ControllerTask, LedTask), then starts them. loop() sleeps
    forever via vTaskDelay(portMAX_DELAY).
    The CLI's ledtest command now sends a ControllerEvent to the controller
    queue and blocks on the CLI response queue. The controller orchestrates
    the LED test sequence by sending LedCommands and calling the progress
    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
2026-03-01 simulator: fix native build errors
    Add printf() to the simulator Print class to match the Arduino API
    available on ESP32.
    Fix vAssertCalled linkage in FreeRTOSConfig.h by adding extern "C" for
    C++ translation units, resolving undefined reference at link time.
2026-03-01 simulator: start FreeRTOS scheduler instead of calling loop()
    The main thread is not a FreeRTOS-managed thread, so calling loop()
    which does vTaskDelay() triggers a configASSERT failure. Start the
    scheduler after setup() and let it run the tasks directly, matching
    how Arduino/ESP32 works under the hood.
    Also enable debug builds (-O0 -g3) for the native environment.
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2026-03-08 fix NFC emulation: use deferred ISR instead of dead polling mode
    The emulator used int_pin=-1 ("polling mode") which completely broke
    interrupt processing — digitalRead(-1) always returns 0, so
    st25r3916CheckForReceivedInterrupts() never ran and the RFAL listen
    mode state machine was dead. Only UID worked (hardware anticollision)
    but no data exchange (READ/NDEF), so phones couldn't read the tag.
    Fix: use the real interrupt pin with deferred ISR patches from the
    working esp32-nfc-demo. ISR just sets a flag, rfalWorker() polls it.
    Also adds low-power disable and EOF suppression patches.
2026-03-09 fix: reset badges via DTR toggle before pairing test
    [test_pair.py]
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2026-03-18 fixing serial prints and small visual cleanup
    [main.cpp]
2026-03-18 initial quantum scaffold, including nvs, folder structure, and i2c comms - including dock example code
2026-03-21 Fix: work around HWCDC race conditions causing USB CDC data loss
    The ESP32-S3 HWCDC driver silently discards data during burst
    writes for reasons that aren't entirely clear to me.
    Wrap Serial in a LineBufferedStream that accumulates output in a
    4KB buffer and drains to HWCDC in single large write()
    calls, minimizing the number of write calls.
    Three drain triggers keep output responsive:
    - flush(): unconditional, used by CLI poll loop for echo/prompt
    - Newline + elapsed time: drains on '\n' if >20ms since last
    drain, so progressive output (e.g. ledtest) appears in real
    time while burst output (e.g. help) accumulates
    - Background FreeRTOS timer: drains if data sits idle for >50ms,
    ensu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
    [main.cpp]
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2026-03-27 Formatting and single dock logic bug
    [code.py]
2026-04-14 feat: add GxEPD2 e-ink display driver (GDEH0154D67 200x200)
    Integrate 1.54" BW e-ink display sharing HSPI bus with NFC ST25R3916.
    Pins: CS=IO41, DC=IO42, RST=IO45, BUSY=IO46. Adds einktest CLI command.
2026-04-14 feat: add graceful e-ink display detection with BUSY pin probing
    Detect display presence via SSD1681 BUSY pin after hardware reset.
    Adds einkAvailable() guard and protects einktest CLI command when
    no display is connected.
2026-04-14 feat: add DisplayTask with command types, queue, and e-ink rendering
    Create DisplayCommand (ShowLogo, ModeChange, NfcScan, PairResult,
    SocialProgress) with per-type timeouts that auto-revert to the nsec
    logo via a FreeRTOS software timer. DisplayTask renders centered text
    using FreeMonoBold9pt7b on the 200x200 e-ink display with paged
    drawing. Add display queue depth and task priority to badge_config.h.
2026-04-14 feat: dynamic e-ink display with NFC status, social progress, and auto-revert
    - DisplayTask with command queue shows mode changes, scan results, pair
    outcomes, and social progress with per-event timeouts (5-15s)
    - Graceful missing-display detection via SSD1681 soft-reset + BUSY pin
    - Controller tracks NFC mode for toggle behavior; always updates display
    on button press to prevent stale screens
    - NFC task sends scan UIDs and pair results to display queue
    - Boot logo moved from einkInit() to DisplayTask for consistent rendering
    [main.cpp]
2026-04-15 Fixed mangled button mappings from merge conflicts
2026-04-24 challenges: Add the mystery string challenge
    The purpose of the challenge is to explore different encoding modes on a
    serial bus.
    The intended solution involves some soldering to test points and
    capturing the serial output, but extracting the string blob through
    reverse engineering is a possible alternative.
    The analysis and decoding of the string should be the same regardless
    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
2026-04-25 storage: add NVS-backed user config (name, favorite color, brightness)
    New nvs_config module stores user preferences in a dedicated "config"
    NVS namespace: display name (up to 64 chars), favorite RGB color, and
    LED brightness.
2026-04-25 network: add WiFi AP portal task with captive portal and REST API
    PortalTask runs a SoftAP (SSID: NSEC-XXXX based on MAC), a DNS
    server for captive portal redirect, and an ESPAsyncWebServer serving
    a config page. REST endpoints:
    GET /api/config — current user config
    GET /api/social — social progress
    POST /api/config — save name, color, brightness
    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
2026-04-25 portal: show max levels for progress indicators
    Currently, all attributes go to 255. If this changes, we can
    expose the max levels though the API.
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2026-04-25 portal: attempt at implementing NFC wifi access
    UNTESTED; need to fix my badge's antennae.
2026-04-25 portal: WPA2-protect the portal with NVS-persisted credentials
    Replace the open WiFi AP with a WPA2-PSK protected one. On first portal
    activation, the controller task generates a unique SSID (NSEC-XXYYZZ
    from the last 3 MAC bytes) and a random 10-character alphanumeric
    passphrase using the hardware TRNG (esp_random with
    bootloader_random_enable for true entropy before WiFi is active).
    Credentials are persisted in NVS and reused across reboots.
    The credentials flow through the existing queue architecture: the
    controller embeds them in PortalCommand and NfcCommand structs (using
    typed unions for command-specific parameters), so the portal and NFC
    tasks receive them without shared state. The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
2026-04-25 Clean-up CLI to only add list-contacts
    The other commands added during the development of this branch
    were helpers for debugging. I think `list-contacts` is still
    fun for users, but i'm not attached to it if it doesn't fit
    into the intended UX.
2026-04-25 animation: add JSON-driven LED animation engine
    Introduces a field-based LED animation system that replaces hardcoded
    C++ animation structs with JSON definitions loaded from SPIFFS.
    The engine models animations as virtual light sources ("tracks") that
    move across a 2D plane mapped to the badge's 18 WS2812 LEDs. Each
    track has independently animated motion, color, radius, and intensity
    using composable behaviors (static, orbit, ping-pong, noise drift,
    Lissajous, Catmull-Rom spline, hue cycle, palette, breathe, etc.).
    Key design decisions:
    - Field evaluation in linear RGB for physically correct additive light
    mixing, with Oklab perceptual blending available for color
    interpolation.
    - Noi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
    [led_preview.py, main.cpp]
2026-04-25 animation: add LED animation descriptions
    Adds JSON animation definitions for the badge's LED engine:
    boot, smooth_glow, rainbow, splotches, cycles, burning, flow,
    gold_calm, pink_gold_circling, wifi_portal, and three favorite-color
    variants (fav_orbs, fav_breathe, fav_noise).
2026-04-25 fix: remove USB CDC serial wait that blocks boot for up to 5.5s
    The setup() function waited up to 5 seconds for USB serial enumeration
    plus an unconditional 500ms "stability" delay before initializing any
    hardware. This made cold boot feel sluggish and unresponsive since the
    boot animation couldn't start until the wait expired.
    On soft reboot the USB connection is already established so the wait
    returned immediately, making the difference very noticeable.
    The wait only served to avoid losing early Serial.println() debug
    output; it has no effect on badge functionality.
    [main.cpp]
2026-04-25 animation: rework intensity pipeline and improve dithering
    A configurable intensity_curve exponent (default 1.5) is applied to the
    intensity parameter, then divided by gamma so the output stage doesn't
    crush the bottom of the range a second time. The effective output
    contribution is pow(param, intensity_curve). The curve shapes how the
    animation "knob" feels while gamma pre-compensation keeps low values
    visible.
    This mirrors the existing fade-in envelope pre-compensation
    (pow(fade, 1/gamma)) which prevents gamma from turning a linear ramp
    into a bottom-heavy curve.
    - Temporal dithering improvements -
    Each RGB channel now uses a different frame multiplier (251/127/31) in
    the noise hash so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
2026-04-25 feat: play wifi_portal animation during portal and support live palette updates
    Start the wifi_portal LED animation when the WiFi portal is activated and
    turn it off when the portal shuts down. Add a PaletteUpdate LED command so
    that changing the user's favorite color via the portal updates the running
    animation in real time. Fix resolvePalette to accept RGB directly so
    achromatic colors like white are no longer mapped to red.
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2026-04-25 refactor: centralize NFC LED control in the controller
    NfcTask no longer pokes the LED queue. Mode start/stop colours
    (white/cyan/orange/off) are now set by ControllerTask alongside the
    NfcCommand it issues, and async results (scan complete, pair outcome)
    are sent back as new ControllerEvent variants (NfcScanResultEvent and
    NfcPairResultEvent) which the controller turns into ProgressFlash
    commands.
    Drops the LedCommand queue dependency from NfcTask entirely.
    [main.cpp]
2026-04-25 animation: render progress flash through the field engine
    Replaces the hand-rolled rgbSetPixel-based flash routine with a
    field-system animation built at the moment a ProgressFlash command is
    processed.
    buildProgressFlash() places one static light per LED for the first
    pixelCount LEDs, each with a small (0.07) radius so colours stay
    localized to each LED, and a Breathe intensity envelope.
    Held flashes loop forever; one-shot flashes stop after 4s.
    Bumps animation::max_lights from 16 to 18 so a full-ring flash can
    afford one light per LED. Extracts the engine-driving loop from
    runAnimation into a shared driveAnimation() helper that runProgressFlash
    also reuses.
    The LedCommand{ProgressFlash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
2026-04-25 animation: render solid colours as a soft per-LED breathe
    All Solid* commands (SolidRed/Green/Blue/White/Orange/Cyan and SolidColor)
    now go through a buildSolidBreathe(color) animation instead of
    rgbSetAll + delay(1000).
    Each command builds an 18-track AnimationDef with one static-position
    light per LED, a tight radius, and a Breathe intensity (0.6..1.0 over
    2.5s). Per-LED phase offsets stepped by 2π·(1−1/φ) keep the LEDs out of
    phase with each other, producing a soft sparkle rather than a
    synchronised pulse.
    Side benefit: the LED task is no longer parked in a 1-second delay()
    after a solid command, so subsequent commands take effect at the next
    animation frame instead of up to a seco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
2026-04-25 controller: explicit state machine with timeouts and idle animations
    Replaces the scattered _nfcMode/_portalActive/_socialActive flags with
    a single State enum (Idle, Social, NfcReader, NfcEmulator, NfcPair,
    Portal).
    Every transition routes through enterIdle/enterSocial/
    enterNfcMode/enterPortal, each starting with cleanupCurrent() so the
    previous state's NFC and portal-task resources are released exactly
    once.
    State transitions
    -----------------
    * Up — Portal <-> Idle
    * Down — NfcPair <-> Idle
    * Left — NfcReader <-> Idle
    * Right — NfcEmulator <-> Idle
    * B — any -> Social; in Social, B-double-press toggles hold
    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
    [main.cpp]
2026-04-25 dock interaction priority fix
    [code.py]
2026-04-25 animation: clamp negative intensity before powf to prevent NaN
    A breathe scalar with amplitude > base (e.g. base=0.3, amplitude=0.5)
    evaluates negative for part of its cycle. Feeding that into
    powf(value, intensity_curve / gamma) returns NaN because the exponent
    is fractional.
    NaN then poisons the rest of the pipeline:
    - The `light.intensity <= 0.0f` short-circuit in evaluateField()
    fails because any comparison with NaN is false, so the NaN flows
    into the additive accumulator.
    - The clamp/scale logic in evaluateField() is also comparison-based
    and lets NaN through.
    - In ditheredOutput(), neither `corrected < 0.0f` nor
    `corrected > 255.0f` catches NaN, and static_cast<u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
2026-05-04 feat: badge v2 PCB design with panelization support
    Updated schematic and PCB layout for badge v2 revision. Added
    panelization project with JLCPCB production files, panelize script,
    and board SVG artwork.
    [BOM-nsec-badge-2026-panel.csv, button.kicad_sch, e-ink_display.kicad_sch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]
2026-05-04 feat: add SAO designs (Sun, Tree, Robotplant)
    Three SAO (Shitty Add-On) KiCad projects with JLCPCB production files
    and panelization scripts.
    [BOM-Sao_SUN.csv, BOM-Sao_Tree-leaf_panel.csv, BOM-Sao_Tree_panel.csv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]
2026-05-07 cli and behaviour fix
    [main.cpp]
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
